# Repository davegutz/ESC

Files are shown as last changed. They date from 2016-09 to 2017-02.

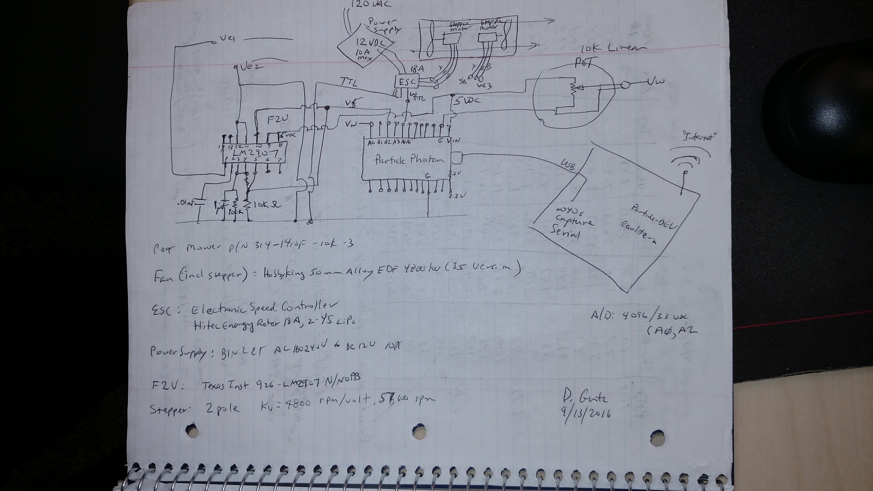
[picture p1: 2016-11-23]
Problem/2016-10-06 06.58.16.jpg

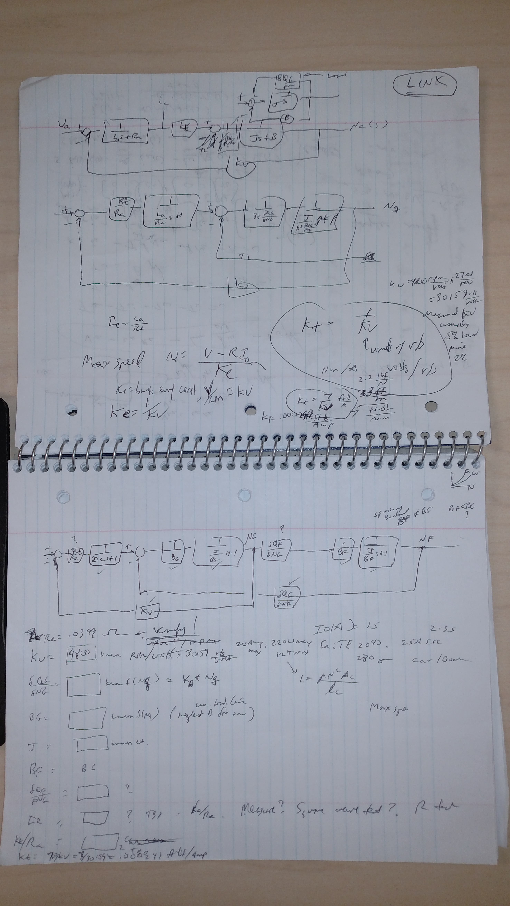
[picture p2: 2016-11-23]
Problem/2016-10-17 16.06.20.jpg

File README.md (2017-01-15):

Configuring Visual Studio Code IDE to run with Particle Photon
  https://www.hackster.io/gusgonnet/use-visual-studio-code-for-your-particle-development-needs-9e23bc
1.  Update particle IDE
    https://binaries.particle.io/cli/installer/windows/ParticleCLISetup.exe
	npm install -g particle-cli
2.  Download/install VS Code
	a.   Install from https://code.visualstudio.com/
	b.  Execute from command line providing proect path:
		$ code /home/gustavo/myParticleProject
		This can also be done from File menu of VS IDE
	c.  Install C/C++ Extension from Getting Started of https://code.visualstudio.com/docs/languages/cpp
	d.	Configure the c_cpp_properties.json file following instruction from same place of previous line
		browse to a .cpp file that has a #include.   You will see squiggly green line underneath.  Click on the text that is undelined.
		click the lightbulb that appears.   Click "Add include path to settings"
	e.  Generate a tasks.json file following instructions same place
		open Command Palette (ctrl-shift-P)
		select Tasks:  Configure Task Runner
		select Others
		Change "command" to the cmd line expression used to build ""
In the tasks.json (.vscode folder in MYWINDCODE) make it look like following (for usb flashing)
{ 
"version": "0.1.0", 
"command": "particle", 
"isShellCommand": true, 
"args": [], 
"showOutput": "always", 
"echoCommand": true, 
"tasks": [ 
{ 
    "taskName": "compile", 
    "suppressTaskName": false, 
    "isBuildCommand": true,
    "args": ["photon", "${workspaceRoot}", "--saveTo", "${workspaceRoot}/firmware.bin"]             
}, 
{ 
    "taskName": "flash",             
    "suppressTaskName": false, 
    "isTestCommand": true, 
    "args": ["--usb", "firmware.bin"] 
}    
]     
} 

	f.  Format your code by right-click - Format Code
	g.  Build by ctrl-shift-B
	h.  Flash by ctrl-P, task - <space> - <flash>
		Photon must be blinking yellow by pushing both buttons simultaneously, releasing RESET, wait for purple then yellow

1.       If compile in DEV and no status message returned, probably are not connected to wifi.  Particle-DEV does not work over GE network.

2.       Wifi connection problems at work usually fixed by changing Odyssey from BLUESSO to Internet.   Particle-DEV does not work over GE network.

4.       Photon does not connect for flash:   need to get closer to Internet wifi.   Photon wifi a little weak.

5.       Coolterm “Port not found.”  Photon USB not visible.  Restart Coolterm.   Unplug Photon USB and replug.   Rescan ports in Coolterm-Connection-Options.   Prevent this by disconnecting CoolTerm before servicing Photon.

6.       Red error window pops in DEV.  Restart DEV.

Compile Photon.
	- use MS Visual Studio IDE
	- ctr-Shift-B #to build
	- ctrl-P task flash #to flash
Communicate with photon real time
	- Cool Term - Connection - Send String
		b    # bare photon toggle
		t    # close loop with model toggle
		c    # closed loop toggle
		P 20 # request potThrottle 20 deg, open or closed work
		V 	 # run VECT toggle
		R 	 # run RAMP toggle
		f 	 # run freq resp toggle

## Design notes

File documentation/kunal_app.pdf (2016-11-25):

ECE 480 – Application Note – Kunal Verma | 4/2/2010

# Configuring a Frequency to Voltage Converter

by

## Kunal Verma

## Design Team 5

## ECE 480 - Spring 2010

## Michigan State University

## _______________________________ Introduction

Measuring frequency for use in signal processing is a very important tool for system

engineers. The most familiar type of tachometer is the speedometer used in motor

vehicles. One of the easiest ways to do this is to use a circuit that takes a varied frequency

input and produces a voltage corresponding to each frequency in the range of its

measuring capacity. By creating a linear relationship between frequency and voltage a

designer can vary easily integrate frequency measurement into the application of their

choice. In this article we will look at a method for designing an easy to use frequency to

voltage converter using the National Semiconductor LM2907/LM2917 series ICs.

## _________________________________ LM2907N

The specific IC model that we will analyze in this article is the LM2907-N, a 14-pin DIP

package that contains a comparator, capacitor charge pump, and op-amp/transistor

amplification stage. The schematic for the device can be seen below:

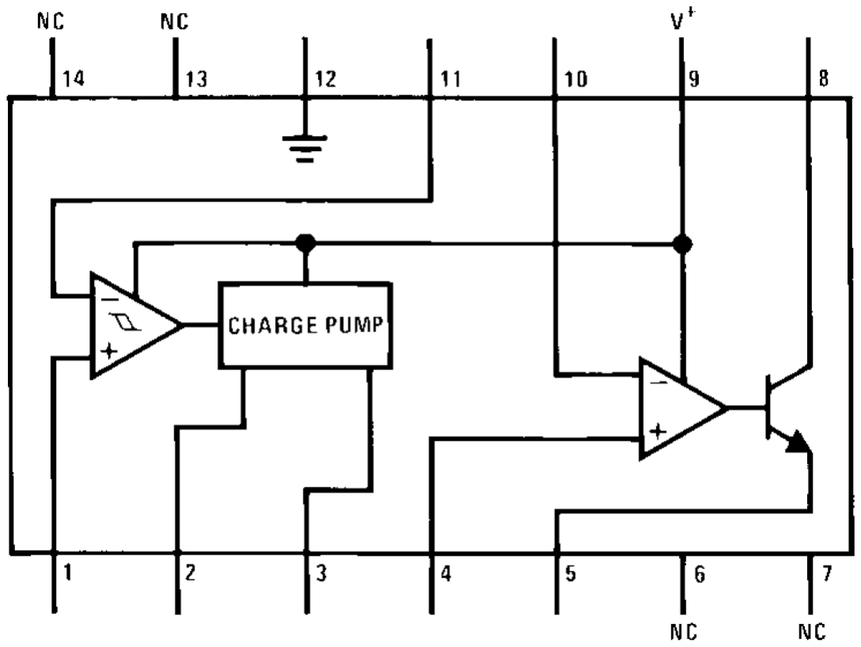
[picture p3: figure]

Figure 1: Circuit Layout for LM2907-N

The first part of the processing chain is the comparator. By grounding the negative

differential input of the comparator we create a zero-crossing detector. Applying an AC

signal with no DC offset and common grounding to the positive terminal will produce a

square wave output.

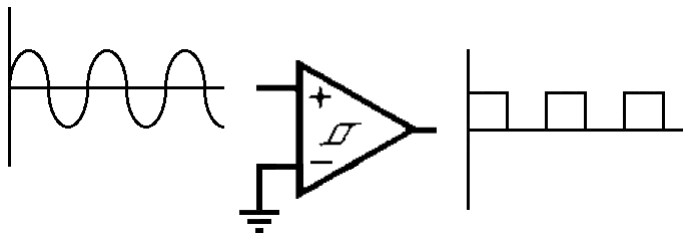
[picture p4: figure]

Figure 2: Output response of a zero-crossing detector

From this square wave the charge pump uses a timing capacitor to provide the charge and

discharge for the charge pumping action. The charging capacitor is attached to pin 2.

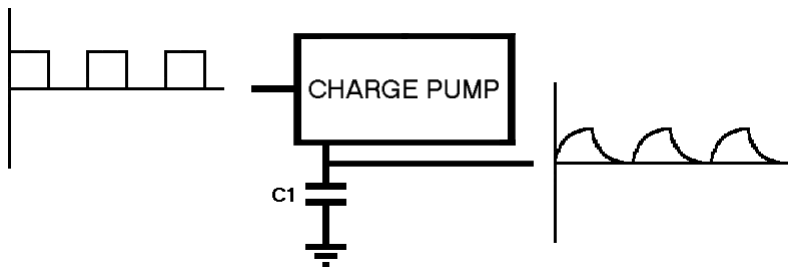
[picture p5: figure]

Figure 3: Voltage response of the timing capacitor C1

The amplitude of the resulting signal is | | ⁄ and a change in voltage of this magnitude
is experienced by the capacitor every | ( ⁄ | ) seconds. This results in a time averaging

current through the capacitor:

(1)

This current is then mirrored on the output of the charge pump where it can be fed to a

grounding resistor and filtered by a second capacitor for smoother response. The output

voltage across the resistor can then be calculated using Ohm’s law and Eq (1):

(2)

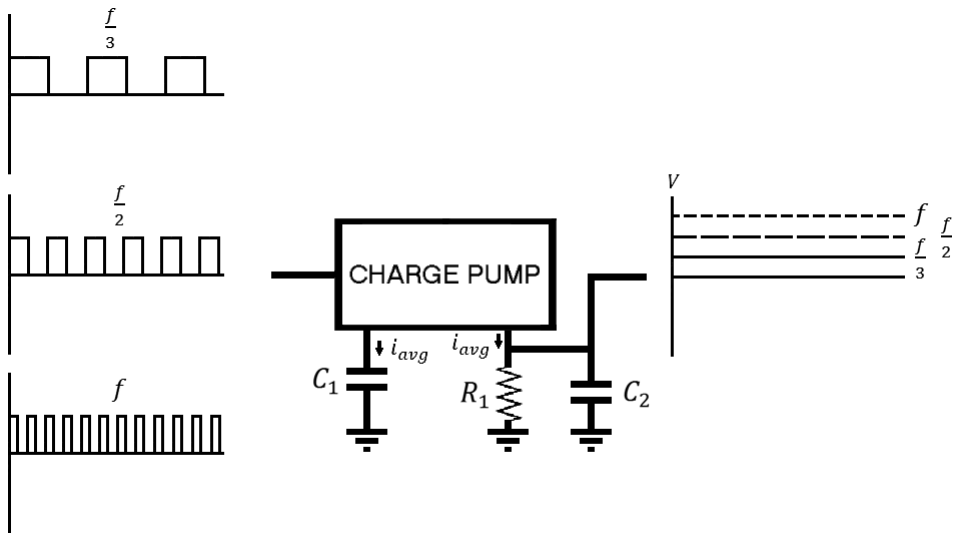
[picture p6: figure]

Figure 4: Expected output response of a charge pump

As we can see the output voltage is entirely affected by the frequency of the input signal

in a very simple linear relationship. In our application Vcc = 5V and we wish to see a

maximum output voltage of 5V as well, therefore we are given a simple design equation

relating our component values to the maximum expected frequency of our input signal.

(3)

Choosing a value for is relatively trivial. For low frequency signal acquisition the

general rule of thumb is to increase discharge time as much as possible, this reduces

response time for the frequency to voltage converter but it also stabilizes the output

voltage variation.

## __________________________________ Example

For our project we required a frequency to voltage converter with a 450 Hz range, and

output voltage of 5V. Using the assumption from before ( | )we can easily find

a relationship between the timing capacitor and output resistor using Eq (3).

choosing | nF:
( | )
The closest available resistor for use in our example is a 68 | resistor. Our

maximum frequency then becomes:

( | ) ( | )

Hz

Using Eq (2) we can also very easily calculate the linear relationship between input

frequency and output voltage, with DC corresponding to 0V as a minimum limit and

corresponding to Vcc as a maximum limit:

In order to compensate for any irregularities in the test circuit we choose to include

calibration variables. These variables will allow us to adapt our model for use in

integration with a microcontroller:

(

)

## _____________________________ Benchmarking

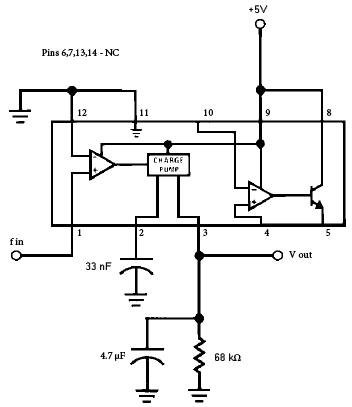
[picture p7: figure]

The test circuit used for the analysis of the

frequency to voltage converter is shown to

the right. With our compensation variables

set to 0 we expected an f-V relationship of
(

) .

The input signal for testing was a 1Vpp

Sine wave with 0-DC and variable

frequency (0 – 400 Hz). Frequencies

beyond 400 Hz showed a flat response, a

result we had not expected. The expected

and measured voltage response is shown in

Figure 6 below. Comparison between the

expected and measured functions led to

determination of the calibration variables:

and

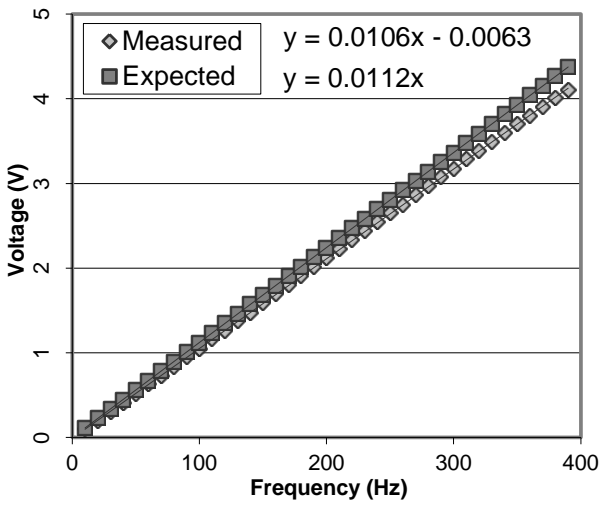
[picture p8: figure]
Voltage (V); Frequency (Hz); Measured Expected

Figure 6: Testing Results

Figure 5: Test Circuit for 450 Hz Frequency to

## _________________________________ Resources

National Conductor LM2907 Datasheet (http://www.national.com/ds/LM/LM2907.pdf)

The Analysis and Design of Linear Circuits – 6

th
Edition (Thomas and Albert, 2006)

Charge Pump Circuit Design – 1

st
Edition (Pan, 2006)

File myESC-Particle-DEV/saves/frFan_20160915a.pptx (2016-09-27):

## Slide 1

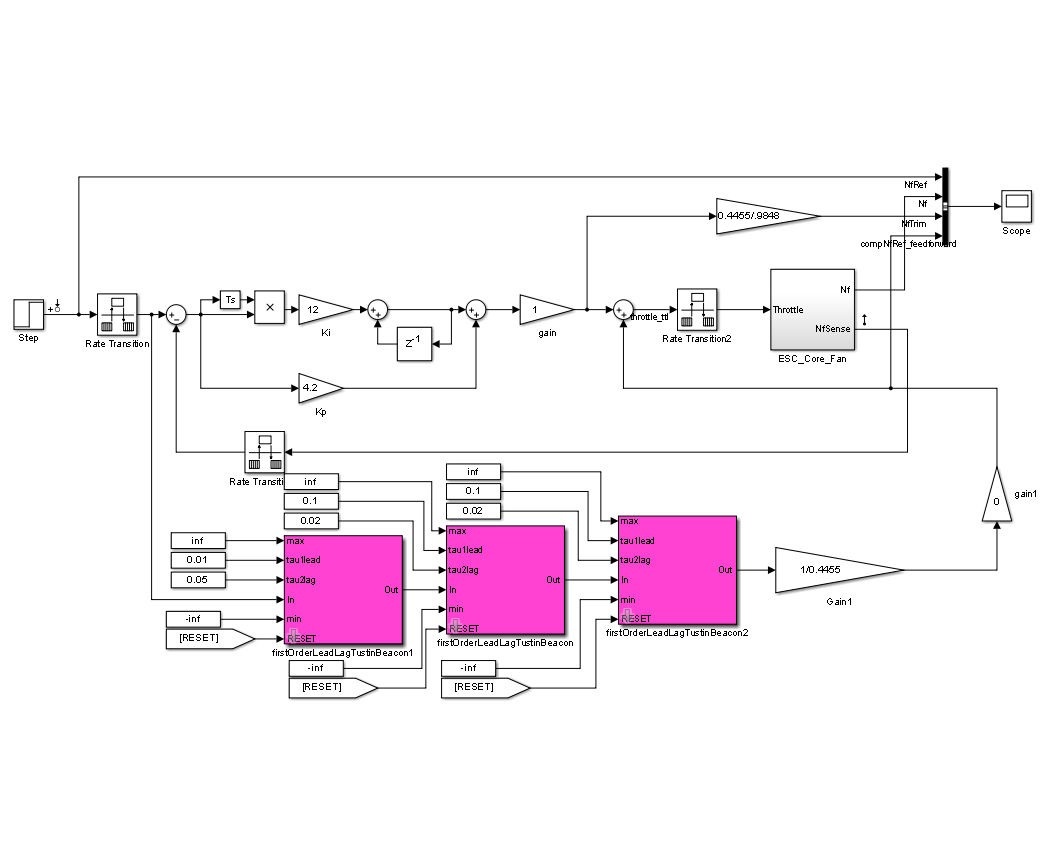
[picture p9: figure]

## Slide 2

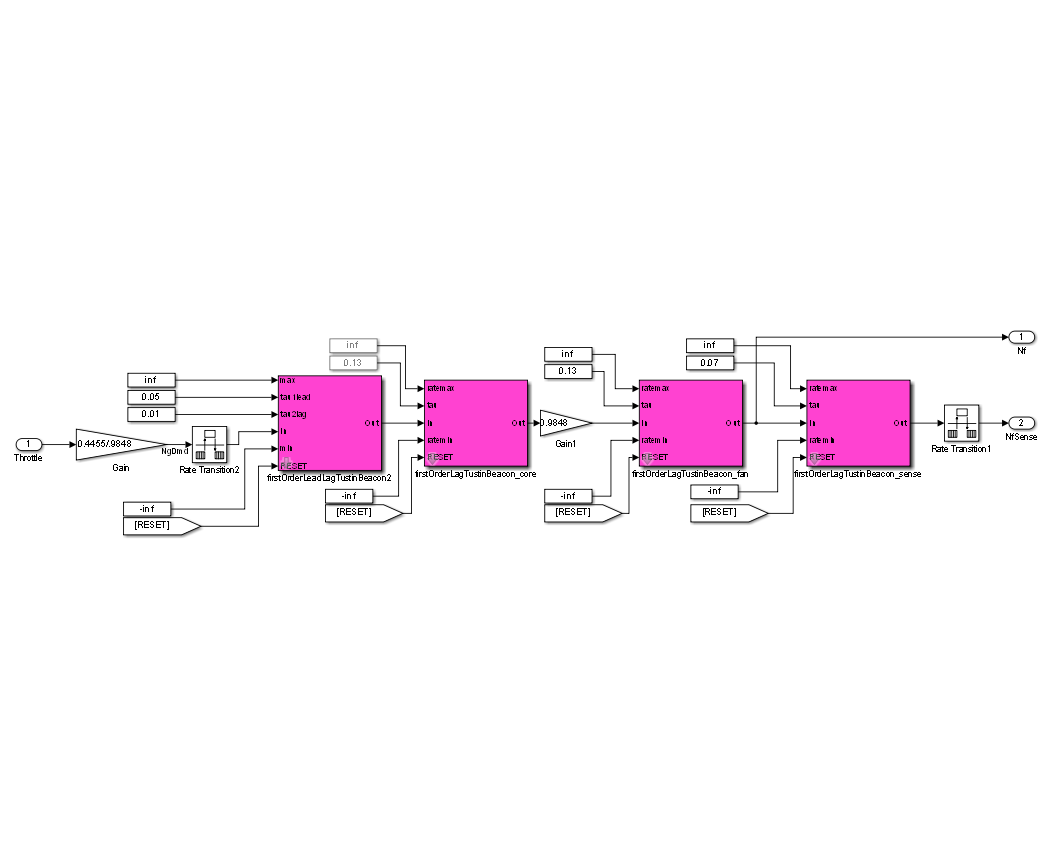
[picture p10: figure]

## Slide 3

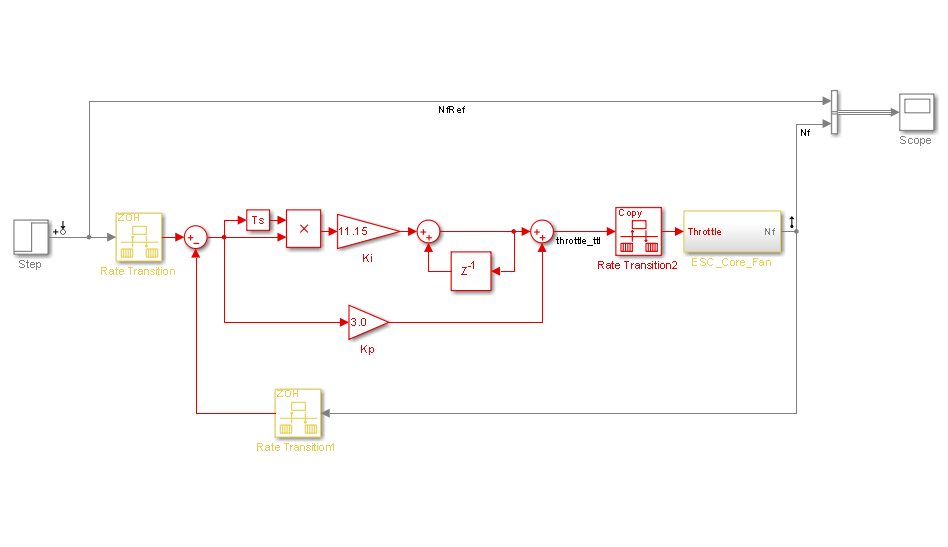
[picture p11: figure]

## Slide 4

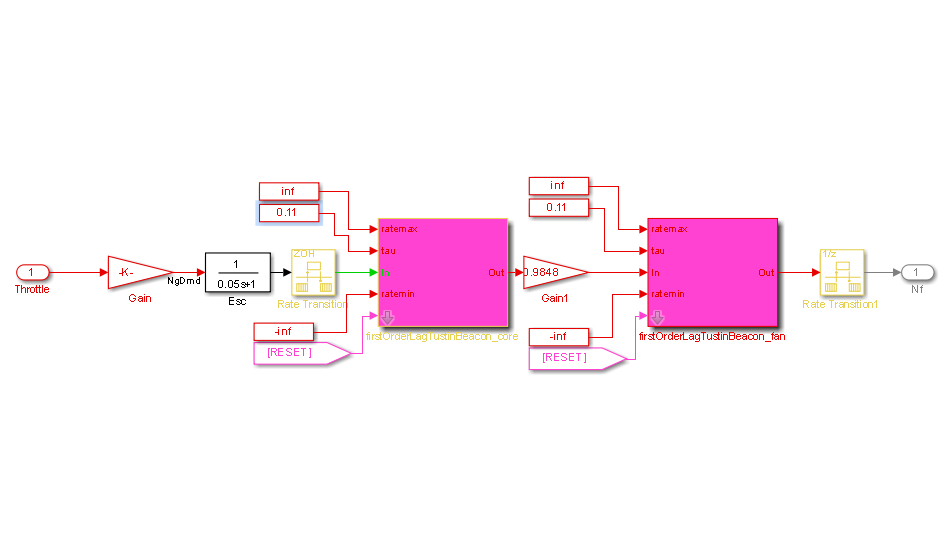
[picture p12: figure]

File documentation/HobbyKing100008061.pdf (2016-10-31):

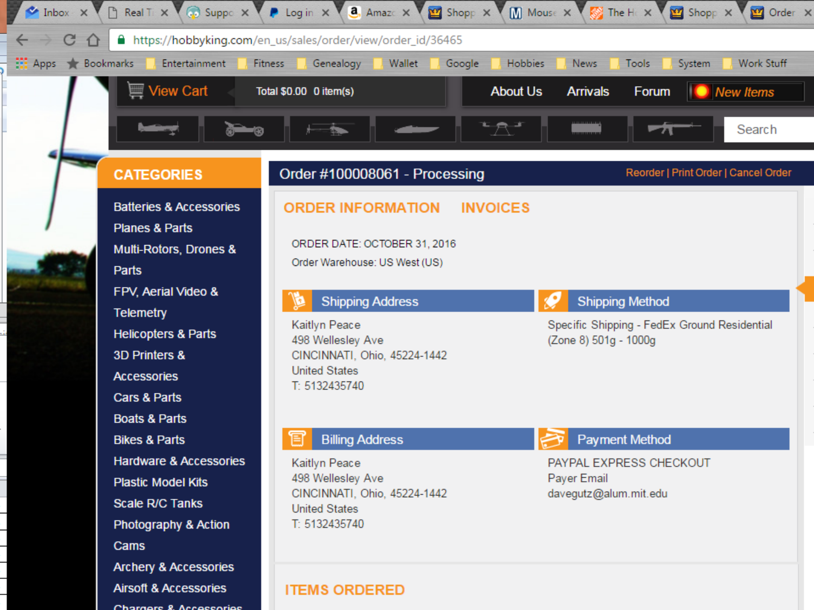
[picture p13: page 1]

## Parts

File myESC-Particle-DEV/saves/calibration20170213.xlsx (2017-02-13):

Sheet: Ard0_Turn0_ESC0_G0b_T0a
Description | Set Nt | TTL, ms | throttleFlt, deg | v4, vdc | Charger V, vdc | Charger I, A | Tng, micros | Ttur, micros |  | Charger Pwr, W | Throttle, deg | ln(Throttle) | FreqNg, Hz | FreqTur, Hz | Ng, RPM | Nt, RPM | Ng, % | Nt, % | Throttle, deg | Charger Pwr, W | Ng Pwr, W | Ng Pwr, SHP | Ng Total Torque, ft-lbf | Ng Torque, ft-lbf | Thrust, N | Thrust Power, W | Overall Efficiency | Vw, m/s | Vw, mph | Vt, m/s | Lambda tip speed ratio | dCpdLambda | simulate vpot from throttle | model throttle from vpot | Model Ng from Model Throttle, rpm | Model Ng from Model Throttle, % | Model pcntRef from Model Ng, % | Model Ng from pcntRef at RESET, % | Model Nt from Model Ng, % | Model Nt from Model Ng, rpm | Model Qg from Model Ng, ft-lbf | Model PwrG from Model Ng*Q, shp | Model dQgdNg, ft-lbf/rpm | Model TauG | Model dQtdNt, ft-lbf/rpm | Model TauT from wind | v4, vdc
DC Power Overhead | n/a | 1.03 | 6.07 | 0.0032 | 12.24 | 0.019 | 1e+32 | 1e+32 |  | 0.2 | 6.07 | 1.8027 | 1e-26 | 1e-26 | 6e-25 | 0 | 1.302083333e-27 | 0 | 6.066122035 | 0.23 | 0 | 0.0000 | 0.00000 | 0.00000 | 9.768434808e-87 | 9.469612349e-129 |  | 1.938818764e-42 | 4.362342218e-42 | 0 | 0.00 |  | 0.169 | 6.066 | 0.00 | 0.00 | -17.48 | 0.03 |  | 0 |  |  |  |  |  |  | 0.0032
Lowest Ng | n/a | 1.05 | 9 | 0.0024 | 12.15 | 0.34 | 7080 | 1e+32 |  | 4.1 | 9 | 2.1972 | 141.2429379 | 1e-26 | 8474.576271 | 6e-25 | 18.39100753 | 1.302083333e-27 | 9 | 4.07 | 3.83769 | 0.0051 | 0.00319 | 0.00000 | 0.028 | 0.04 | 1.1 | 3.25 | 7.3 | 1.727875959e-27 | 5.309152921e-28 |  | 0.250 | 9.000 | 4918.12 | 10.67 | -7.36 | 10.70 |  | 0 | 0.00000 | 0.00000 | 1.105647023e-07 |  |  |  | 0.0024
First Nt | tbd | 1.11 | 20 | 0.069 | 12.14 | 0.86 | 4040 | 68000 |  | 10.5 | 20 | 2.9957 | 247.5247525 | 14.70588235 | 14851.48515 | 882.3529412 | 32.22978548 | 1.914828431 | 20 | 10.45 | 10.22 | 0.0137 | 0.00485 | 0.00166 | 0.148 | 0.56 | 5.4 | 7.55 | 17.0 | 2.5 | 0.34 |  | 0.556 | 20.000 | 14872.75 | 32.28 | 13.10 | 32.29 | 13.1 | 6038.54 | 0.00194 | 0.00548 | 3.729326807e-07 | 0.100 |  |  | 0.069
Dynamic Nt #1 | 16 | 1.14 | 25 | 0.51 | 12.14 | 1.13 | 3680 | 8500 |  | 13.7 | 25 | 3.2189 | 271.7391304 | 117.6470588 | 16304.34783 | 7058.823529 | 35.38269928 | 15.31862745 | 25 | 13.72 | 13.49 | 0.0181 | 0.00583 | 0.00264 | 0.196 | 0.85 | 6.2 | 8.68 | 19.5 | 20.3 | 2.34 |  | 0.694 | 25.000 | 17654.58 | 38.31 | 18.82 | 38.33 | 18.8 | 8674.185965 | 0.00308 | 0.01034 | 4.462516013e-07 | 0.084 | -1.105608516e-07 | 0.339 | 0.51
Dynamic Nt #2 | 20 | 1.19 | 35 | 0.801 | 12.11 | 1.838 | 2980 | 5420 |  | 22.3 | 35 | 3.5553 | 335.5704698 | 184.501845 | 20134.22819 | 11070.1107 | 43.69407159 | 24.02367774 | 35 | 22.26 | 22.03 | 0.0295 | 0.00770 | 0.00452 | 0.369 | 2.20 | 9.9 | 11.92 | 26.8 | 31.9 | 2.67 |  | 0.972 | 35.000 | 21849.23 | 47.42 | 27.45 | 47.43 | 27.4 | 12648.40654 | 0.00518 | 0.02155 | 5.568072553e-07 | 0.067 | -1.517220518e-07 | 0.247 | 0.801
Dynamic Nt #3 | 25 | 1.30 | 54 | 1.167 | 12.06 | 3.18 | 2390 | 3740 |  | 38.4 | 54 | 3.9890 | 418.4100418 | 267.3796791 | 25104.60251 | 16042.78075 | 54.4804742 | 34.81506239 | 54 | 38.35 | 38.12 | 0.0511 | 0.01069 | 0.00750 | 0.716 | 5.94 | 15.5 | 16.59 | 37.3 | 46.2 | 2.78 |  | 1.500 | 54.000 | 27255.18 | 59.15 | 38.56 | 59.15 | 38.6 | 17770.27059 | 0.00857 | 0.04450 | 6.992882824e-07 | 0.054 | -2.112400453e-07 | 0.177 | 1.167
Dynamic Nt #4 | 36 | 1.36 | 64 | 1.275 | 12.03 | 3.96 | 2170 | 3260 |  | 47.6 | 64 | 4.1589 | 460.8294931 | 306.7484663 | 27649.76959 | 18404.90798 | 60.00384025 | 39.94120654 | 64 | 47.64 | 47.41 | 0.0636 | 0.01208 | 0.00889 | 0.956 | 9.17 | 19.2 | 19.18 | 43.2 | 53.0 | 2.76 |  | 1.778 | 64.000 | 29373.23 | 63.74 | 42.92 | 63.75 | 42.9 | 19777.02234 | 0.01011 | 0.05657 | 7.551124993e-07 | 0.050 | -2.441650521e-07 | 0.153 | 1.275
Dynamic Nt #5 | 45 | 1.50 | 90 | 1.597 | 11.95 | 5.94 | 1860 | 2690 |  | 71.0 | 90 | 4.4998 | 537.6344086 | 371.7472119 | 32258.06452 | 22304.83271 | 70.00448029 | 48.40458488 | 90 | 70.98 | 70.75 | 0.0949 | 0.01545 | 0.01226 | 1.518 | 18.35 | 25.8 | 24.17 | 54.4 | 64.2 | 2.658 |  | 2.500 | 90.000 | 33623.41 | 72.97 | 51.66 | 72.97 | 51.7 | 23803.85519 | 0.01356 | 0.08682 | 8.67131732e-07 | 0.043 | -3.076831315e-07 | 0.122 | 1.597
Dynamic Nt #6 | 50 | 1.69 | 125 | 1.95 | 11.84 | 8.59 | 1620 | 2210 |  | 101.7 | 125 | 4.8283 | 617.2839506 | 452.4886878 | 37037.03704 | 27149.32127 | 80.3755144 | 58.91779789 | 125 | 101.71 | 101.47 | 0.1361 | 0.01930 | 0.01611 | 2.298 | 34.16 | 33.6 | 29.73 | 66.9 | 78.2 | 2.629 |  | 3.472 | 125.000 | 37718.72 | 81.85 | 60.08 | 81.85 | 60.1 | 27683.96023 | 0.01733 | 0.12449 | 9.750692614e-07 | 0.038 | -3.785302413e-07 | 0.099 | 1.95
Dynamic Nt #7 | 52 | 1.86 | 155 | 2.26 | 11.66 | 12.52 | 1430 | 1900 |  | 146.0 | 155 | 5.0434 | 699.3006993 | 526.3157895 | 41958.04196 | 31578.94737 | 91.05477855 | 68.53070175 | 155 | 145.98 | 145.75 | 0.1955 | 0.02447 | 0.02128 | 3.341 | 59.89 | 41.0 | 35.85 | 80.7 | 90.9 | 2.536 | -0.425 | 4.306 | 155.000 | 40400.42 | 87.67 | 65.59 | 87.67 | 65.6 | 30224.73471 | 0.02004 | 0.15419 | 1.045749028e-06 | 0.036 | -4.564246037e-07 | 0.082 | 2.26
Dynamic Nt #7 | 52 | 1.92 | 165 | 2.34 | 11.56 | 14.28 | 1380 | 1815 |  | 165.1 | 165 | 5.1059 | 724.6376812 | 550.9641873 | 43478.26087 | 33057.85124 | 94.35386473 | 71.74012856 | 165 | 165.08 | 164.84 | 0.2211 | 0.02670 | 0.02351 | 3.717 | 70.29 | 42.6 | 37.82 | 85.1 | 95.2 | 2.517 | -0.400 | 4.583 | 165.000 | 41179.84 | 89.37 | 67.19 | 89.36 | 67.2 | 30963.18996 | 0.02087 | 0.16361 | 1.066291522e-06 | 0.035 | -4.814536392e-07 | 0.078 | 2.34
Max | tbd | 2.00 | 180 | 2.4 | 11.53 | 14.92 | 1368 | 1790 |  | 172.0 | 180 | 5.1930 | 730.994152 | 558.6592179 | 43859.64912 | 33519.55307 | 95.18153021 | 72.74208566 | 180 | 172.03 | 171.80 | 0.2304 | 0.02759 | 0.02440 | 4.425 | 91.30 | 53.1 | 41.26 | 92.8 | 96.5 | 2.339 |  | 5.000 | 180.000 | 42264.57 | 91.72 | 69.42 | 91.71 | 69.4 | 31990.91934 | 0.02204 | 0.17736 | 1.094881102e-06 | 0.034 | -5.253091111e-07 | 0.071 | 2.4
Calibration sheet
1 |  | Calibrate the ESC first |  |  |  |  |  | Key | User Inputs
2 |  | Update the Arduino software |  |  |  |  |  |  | Derived
3 |  | Run the points below |  |  |  |  |  |  | Entry to myCLAW.h and potESC.ino
4 |  | Enter blue highlighted items into myCLaw.h |  |  |  |  |  |  | Entry to myCLAW.h and potESC.ino; same between units
5 |  | Run the frequency response fr_
6 |  | Enter results of fr_ into table lower right corner this sheet
7 |  | Hand tune DELTAV |  |  |  |  |  |  |  |  |  |  |  |  | // Constants always defined - potESC.ino #ifdef Arduino
8 |  | Check that Nt corresponding to entry in column AG lines up with Nt from Z in Tau data |  |  |  |  |  |  |  |  |  |  |  |  | POT_MAX | 5 |  |  | v
 |  |  |  |  |  |  |  |  |  |  |  |  |  |  | F2V_MAX | 5 |  |  | v
Motor | numPoles | 1 |  |  |  |  |  | Inertia Turbine Only (need motor***) |  |  |  |  |  |  | F2V_MIN | 0 |  |  | v
 | Kv | 4800 | rpm/V |  |  |  |  | Rt= | 25 | mm |  |  |  |  | POT_MIN | 0 |  |  | v
 | Vc | 12 |  |  |  |  |  | Mt= | 2.1797 | gm |  |  |  |  | DENS_SI | 1.225 |  |  | kg/m^3
 | Ra | 0.0399 | O |  |  |  |  | Jt= | 0.001548498305 | lbm-in^2 | 1/3*MR^2
 | La | 4.2e-06 | H |  |  |  |  | Rm= | 4.8 | mm | at most |  |  |  | // See calibration<date>.xlsx - myCLAW.h
 | Power | 240 | W max |  |  |  |  | Lm= | 19.0 | mm | at most |  |  |  | RPM_P | 460.8 |  |  | rpm/%
 | Kvrps | 502.7 | r/s / V |  |  |  |  | Mm= | 0.006212622191 | lbm | at most |  |  |  | THTL_MAX | 180 |  |  | deg
 | Kt | 0.0139 | ft-lbf/A |  |  |  |  | Jm | 0.0001092062495 | lbm-in^2 | 1/2*MR^2 |  |  |  | THTL_MIN | 0 |  |  | deg
 | Fn | 0.99 | lbf |  |  |  |  | J= | 0.001657704555 | lbm-in^2 |  |  |  |  | AREA_SI | 0.002121360439 |  |  | m^2
 |  |  |  |  |  |  |  | J= | 1.151183719e-05 | lbm-ft^2 |  |  |  |  | NM_2_FTLBF | 0.738 |  |  | ft-lbf/N-m
LM2907N Circuit |  | vf2v, v |  |  |  |  |  | J= | 3.74268175e-08 | ft-lbf/(rpm/sec) |  |  |  |  | JT | 3.74268175e-08 |  |  | rpm/s / ft-lbf
 | F2V_MIN | 0 |  |  |  |  |  |  |  |  |  |  |  |  | D_SI | 0.055 |  |  | m
 | F2V_MAX | 5 |  |  |  | TBD |  | From fr_a0_t0_e0_g0b_t0a.xlsx |  |  |  |  |  |  | FG_SI | 4.425 |  |  | N
 |  |  |  |  |  |  |  | Nt, % | Calc Ng, % | Meas TauT0, s | Meas QdN, ft-lbf/rpm | Meas dQdN, N-m/rpm
Fan Rotor | Dia | 55 | mm |  |  |  |  | 83.9 | 107.0 | 0 |  |  |  |  | // Ard0_Turn0_ESC0_G0b_T0a - myCLAW.h
 | Dia spinner | 18 | mm |  |  |  |  | 62 | 83.9 | 0.050 |  |  |  |  | P_V4_NT | 0 | 13952.04806 | 27.10040275 | rpm
 |  |  |  |  |  |  |  | 48 | 69.1 | 0.082 | 4.564246037e-07 | -6.187291928e-07 | cal point |  | P_LT_NG | -22473.69517 | 12466.55113 |  | rpm
Air | Dens | 1.225 | kg/m^3 | SLS Std Day |  |  |  | 25 | 44.8 | 0.196 |  |  |  |  | P_NG_NT | -8052.654718 | 0.9475 |  | rpm
 |  |  |  |  |  |  |  | 16 | 35.3 | 0.249 |  |  |  |  | P_NT_NG | 8510.224957 | 1.0550 |  | rpm
Thtl | min | 0 | V Pot |  |  |  |  | -26.6 | -9.6 | 0.5 |  |  |  |  | DCPDL | -0.425 |  |  | none
 | max | 5 | V Pot |  |  |  |  |  |  |  |  |  |  |  | LAMBDA | 2.54 |  |  | none
 | min | 0 | deg Throttle |  |  |  |  |  |  |  |  |  |  |  | DELTAV | 0 |  |  | m/s
 | max | 180 | deg Throttle |  |  |  |  | P_NG_QG | -0.000695441078 | -1.905896073e-08 | 1.317817906e-11 | ft-lbf
Adjust | 1.25 | for 100% Ng at |  | 240 | watts |  |  | matlabTuning.xlsx |  |  |  | tldF=.15, tlgF=.03
 |  |  |  |  |  |  |  | TauT Design, s | Nt, % | TLD_S | LG_S | TLD_L | LG_L |  | xAll | 0.0 | -0.1 | 27.2 | 47.4 | 75.1 | 80.0
 |  |  |  |  |  |  |  | 0 | 83.9 | 0.2 | 4.4 | 0.09 | 5 |  | TLD_S | 0.475 | 0.475 | 0.325 | 0.225 | 0.200 | 0.200 | Scheduled
 |  |  |  |  |  |  |  | 0.02 | 75.1 | 0.2 | 3.75 | 0.09 | 5 |  | LG_S | 2.40 | 2.40 | 2.70 | 3.20 | 3.75 | 4.40
 |  |  |  |  |  |  |  | 0.085 | 47.4 | 0.225 | 3.2 | 0.125 | 4.050 |  | tldF | 0.15
 |  |  |  |  |  |  |  | 0.185 | 27.2 | 0.325 | 2.7 | 0.24 | 3.75 |  | tlgF | 0.03
 |  |  |  |  |  |  |  | 0.344 | -0.1 | 0.475 | 2.4 | 0.42 | 3.6 |  | TLD_L | 0.420 | 0.420 | 0.240 | 0.125 | 0.090 | 0.090 | Fixed lead
 |  |  |  |  |  |  |  | 0.5 | -26.6 | 0.475 | 2.4 | 0.42 | 3.6 |  | LG_L | 3.60 | 3.60 | 3.75 | 4.05 | 5.00 | 5.00

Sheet: Ard1_Turn1x_ESC1_G1b_T1a
Description | Set Nt | TTL, ms | throttleFlt, deg | v4, vdc | Charger V, vdc | Charger I, A | Tng, micros | Ttur, micros |  | Charger Pwr, W | Throttle, deg | ln(Throttle) | FreqNg, Hz | FreqTur, Hz | Ng, RPM | Nt, RPM | Ng, % | Nt, % | Throttle, deg | Charger Pwr, W | Ng Pwr, W | Ng Pwr, SHP | Ng Total Torque, ft-lbf | Ng Torque, ft-lbf | Thrust, N | Thrust Power, W | Overall Efficiency | Vw, m/s | Vw, mph | Vt, m/s | Lambda tip speed ratio | dCpdLambda | simulate vpot from throttle | model throttle from vpot | Model Ng from Model Throttle, rpm | Model Ng from Model Throttle, % | Model pcntRef from Model Ng, % | Model Ng from pcntRef at RESET, % | Model Nt from Model Ng, % | Model Nt from Model Ng, rpm | Model Qg from Model Ng, ft-lbf | Model PwrG from Model Ng*Q, shp | Model dQgdNg, ft-lbf/rpm | Model TauG | Model dQtdNt, ft-lbf/rpm | Model TauT from wind | v4, vdc
DC Power Overhead | n/a | 1.03 | 5.38 | 0.0032 | 12.24 | 0.019 | 1e+32 | 1e+32 |  | 0.2 | 5.38 | 1.6827 | 1e-26 | 1e-26 | 6e-25 | 0 | 1.302083333e-27 | 0 | 5.380330042 | 0.23 | 0 | 0.0000 | 0.00000 | 0.00000 | 9.768434808e-87 | 9.469612349e-129 |  | 1.938818764e-42 | 4.362342218e-42 | 0 | 0.00 |  | 0.149 | 5.380 | 0.00 | 0.00 | -12.59 | 0.04 |  | 0 |  |  |  |  |  |  | 0.0032
Lowest Ng | n/a | 1.04 | 8 | 0.0046 | 12.23 | 0.28 | 8000 | 1e+32 |  | 3.4 | 8 | 2.0794 | 125 | 1e-26 | 7500 | 6e-25 | 16.27604167 | 1.302083333e-27 | 8 | 3.39 | 3.15515 | 0.0042 | 0.00296 | 0.00000 | 0.019 | 0.03 | 0.8 | 2.71 | 6.1 | 1.727875959e-27 | 6.376910601e-28 |  | 0.222 | 8.000 | 4555.17 | 9.89 | -2.93 | 9.92 |  | 0 | 0.00000 | 0.00000 | 2.827231837e-07 |  |  |  | 0.0046 |  | -12.400000
First Nt | tbd | 1.07 | 12 | 0.238 | 12.25 | 0.53 | 5540 | 13200 |  | 6.5 | 12 | 2.4849 | 180.5054152 | 75.75757576 | 10830.32491 | 4545.454545 | 23.50330927 | 9.864267677 | 12 | 6.47 | 6.24 | 0.0084 | 0.00405 | 0.00109 | 0.057 | 0.14 | 2.1 | 4.70 | 10.6 | 13.1 | 2.78 |  | 0.333 | 12.000 | 9211.08 | 19.99 | 6.94 | 20.01 | 6.9 | 3198.660363 | 0.00033 | 0.00058 | 3.695740461e-07 | 0.101 |  |  | 0.238 |  | 72.50000
Dynamic Nt #1 | 16 | 1.09 | 17 | 0.434 | 12.24 | 0.655 | 4900 | 10000 |  | 8.0 | 17 | 2.8332 | 204.0816327 | 100 | 12244.89796 | 6000 | 26.57312925 | 13.02083333 | 17 | 8.02 | 7.78 | 0.0104 | 0.00448 | 0.00151 | 0.083 | 0.23 | 2.9 | 5.65 | 12.7 | 17.3 | 3.06 |  | 0.472 | 17.000 | 13210.65 | 28.67 | 15.42 | 28.69 | 15.4 | 7105.794506 | 0.00196 | 0.00492 | 4.44181543e-07 | 0.084 |  |  | 0.434
Dynamic Nt #2 | 20 | 1.12 | 21 | 0.586 | 12.24 | 0.877 | 4180 | 7500 |  | 10.7 | 21 | 3.0445 | 239.2344498 | 133.3333333 | 14354.06699 | 8000 | 31.15031898 | 17.36111111 | 21 | 10.73 | 10.50 | 0.0141 | 0.00515 | 0.00219 | 0.134 | 0.48 | 4.5 | 7.17 | 16.1 | 23.0 | 3.21 |  | 0.583 | 21.000 | 15637.09 | 33.93 | 20.56 | 33.95 | 20.6 | 9476.15657 | 0.00309 | 0.00920 | 4.89444074e-07 | 0.076 | -1.031450924e-07 | 0.363 | 0.586 | 0.44 | -8.506094887e-08
Dynamic Nt #3 | 25 | 1.15 | 27 | 0.793 | 12.23 | 1.23 | 3540 | 5580 |  | 15.0 | 27 | 3.2958 | 282.4858757 | 179.2114695 | 16949.15254 | 10752.68817 | 36.78201507 | 23.33482676 | 27 | 15.04 | 14.81 | 0.0199 | 0.00615 | 0.00319 | 0.220 | 1.01 | 6.7 | 9.21 | 20.7 | 31.0 | 3.36 |  | 0.750 | 27.000 | 18522.91 | 40.20 | 26.68 | 40.21 | 26.7 | 12295.27891 | 0.00458 | 0.01615 | 5.43275771e-07 | 0.069 | -1.436319949e-07 | 0.261 | 0.793
Dynamic Nt #4 | 36 | 1.23 | 42 | 1.175 | 12.19 | 2.41 | 2770 | 3760 |  | 29.4 | 42 | 3.7377 | 361.0108303 | 265.9574468 | 21660.64982 | 15957.44681 | 47.00661853 | 34.62987589 | 42 | 29.38 | 29.15 | 0.0391 | 0.00948 | 0.00651 | 0.460 | 3.06 | 10.4 | 13.30 | 29.9 | 46.0 | 3.46 |  | 1.167 | 42.000 | 23596.43 | 51.21 | 37.44 | 51.21 | 37.4 | 17251.54263 | 0.00758 | 0.03404 | 6.37916604e-07 | 0.059 | -2.252395456e-07 | 0.166 | 1.175 | 0.289 | -1.295045588e-07
Dynamic Nt #5 | 45 | 1.37 | 67 | 1.624 | 12.13 | 4.27 | 2170 | 2810 |  | 51.8 | 67 | 4.2047 | 460.8294931 | 355.8718861 | 27649.76959 | 21352.31317 | 60.00384025 | 46.33748517 | 67 | 51.80 | 51.56 | 0.0691 | 0.01313 | 0.01017 | 0.956 | 9.17 | 17.7 | 19.18 | 43.2 | 61.5 | 3.206 |  | 1.861 | 67.000 | 28959.21 | 62.85 | 48.81 | 62.84 | 48.8 | 22490.37824 | 0.01127 | 0.06212 | 7.379532029e-07 | 0.051 | -3.424745996e-07 | 0.109 | 1.624
Dynamic Nt #7 | 52 | 1.44 | 79 | 1.786 | 12.09 | 5.32 | 2020 | 2560 |  | 64.3 | 79 | 4.3694 | 495.049505 | 390.625 | 29702.9703 | 23437.5 | 64.45957096 | 50.86263021 | 79 | 64.32 | 64.09 | 0.0859 | 0.01520 | 0.01223 | 1.185 | 12.65 | 19.7 | 21.36 | 48.0 | 67.5 | 3.161 | -0.830 | 2.194 | 79.000 | 30851.07 | 66.95 | 52.82 | 66.94 | 52.8 | 24338.52187 | 0.01270 | 0.07457 | 7.732438699e-07 | 0.048 | -3.858434794e-07 | 0.097 | 1.786
Dynamic Nt #8 | 55 | 1.47 | 84 | 1.842 | 12.08 | 5.63 | 1970 | 2480 |  | 68.0 | 84 | 4.4308 | 507.6142132 | 403.2258065 | 30456.85279 | 24193.54839 | 66.09560068 | 52.50336022 | 84 | 68.01 | 67.78 | 0.0909 | 0.01567 | 0.01271 | 1.278 | 14.17 | 20.8 | 22.17 | 49.9 | 69.7 | 3.142 |  | 2.333 | 84.000 | 31555.77 | 68.48 | 54.31 | 68.47 | 54.3 | 25026.92869 | 0.01324 | 0.07958 | 7.863891339e-07 | 0.048 | -4.021532182e-07 | 0.093 | 1.842 | 0.085 | -4.403155001e-07
Dynamic Nt #8 | 62 | 1.67 | 121 | 2.19 | 11.97 | 8.66 | 1650 | 2040 |  | 103.7 | 121 | 4.7958 | 606.0606061 | 490.1960784 | 36363.63636 | 29411.76471 | 78.91414141 | 63.82761438 | 121 | 103.66 | 103.43 | 0.1387 | 0.02003 | 0.01707 | 2.175 | 31.45 | 30.3 | 28.93 | 65.1 | 84.7 | 2.928 |  | 3.361 | 121.000 | 35746.72 | 77.58 | 63.20 | 77.56 | 63.2 | 29121.02568 | 0.01670 | 0.11369 | 8.645667232e-07 | 0.043 | -5.367879663e-07 | 0.070 | 2.19
Max | tbd | 1.97 | 175 | 2.66 | 11.7 | 14.72 | 1360 | 1620 |  | 172.2 | 175 | 5.1648 | 735.2941176 | 617.2839506 | 44117.64706 | 37037.03704 | 95.74142157 | 80.3755144 | 175 | 172.22 | 171.99 | 0.2306 | 0.02746 | 0.02449 | 4.425 | 91.30 | 53.0 | 41.26 | 92.8 | 106.7 | 2.585 |  | 4.861 | 175.000 | 39983.86 | 86.77 | 72.18 | 86.75 | 72.2 | 33260.23592 | 0.02054 | 0.15633 | 9.436057589e-07 | 0.040 | -7.827245676e-07 | 0.048 | 2.66 | 0.035 | -1.069337643e-06
Calibration sheet
1 |  | Calibrate the ESC first |  |  |  |  |  | Key | User Inputs
2 |  | Update the Arduino software |  |  |  |  |  |  | Derived
3 |  | Run the points below |  |  |  |  |  |  | Entry to myCLAW.h and potESC.ino
4 |  | Enter blue highlighted items into myCLaw.h |  |  |  |  |  |  | Entry to myCLAW.h and potESC.ino; same between units
5 |  | Run the frequency response fr_
6 |  | Enter results of fr_ into table lower right corner this sheet
7 |  | Hand tune DELTAV |  |  |  |  |  |  |  |  |  |  |  |  | // Constants always defined - potESC.ino #ifdef Arduino
8 |  | Check that Nt corresponding to entry in column AG lines up with Nt from Z in Tau data |  |  |  |  |  |  |  |  |  |  |  |  | POT_MAX | 5 |  |  | v
 |  |  |  |  |  |  |  |  |  |  |  |  |  |  | F2V_MAX | 5 |  |  | v
Motor | numPoles | 1 |  |  |  |  |  | Inertia Turbine Only (need motor***) |  |  |  |  |  |  | F2V_MIN | 0 |  |  | v
 | Kv | 4800 | rpm/V |  |  |  |  | Rt= | 25 | mm |  |  |  |  | POT_MIN | 0 |  |  | v
 | Vc | 12 |  |  |  |  |  | Mt= | 2.1797 | gm |  |  |  |  | DENS_SI | 1.225 |  |  | kg/m^3
 | Ra | 0.0399 | O |  |  |  |  | Jt= | 0.001548498305 | lbm-in^2 | 1/3*MR^2
 | La | 4.2e-06 | H |  |  |  |  | Rm= | 4.8 | mm | at most |  |  |  | // See calibration<date>.xlsx - myCLAW.h
 | Power | 240 | W max |  |  |  |  | Lm= | 19.0 | mm | at most |  |  |  | RPM_P | 460.8 |  |  | rpm/%
 | Kvrps | 502.7 | r/s / V |  |  |  |  | Mm= | 0.006212622191 | lbm | at most |  |  |  | THTL_MAX | 180 |  |  | deg
 | Kt | 0.0139 | ft-lbf/A |  |  |  |  | Jm | 0.0001092062495 | lbm-in^2 | 1/2*MR^2 |  |  |  | THTL_MIN | 0 |  |  | deg
 | Fn | 0.99 | lbf |  |  |  |  | J= | 0.001657704555 | lbm-in^2 |  |  |  |  | AREA_SI | 0.002121360439 |  |  | m^2
 |  |  |  |  |  |  |  | J= | 1.151183719e-05 | lbm-ft^2 |  |  |  |  | NM_2_FTLBF | 0.738 |  |  | ft-lbf/N-m
LM2907N Circuit |  | vf2v, v |  |  |  |  |  | J= | 3.74268175e-08 | ft-lbf/(rpm/sec) |  |  |  |  | JT | 3.74268175e-08 |  |  | rpm/s / ft-lbf
 | F2V_MIN | 0 |  |  |  |  |  |  |  |  |  |  |  |  | D_SI | 0.055 |  |  | m
 | F2V_MAX | 5 |  |  |  |  |  | From fr_a1_t1_e1_g1b_t1a.xlsx |  |  |  |  |  |  | FG_SI | 4.425 |  |  | N
 |  |  |  |  |  |  |  | Nt, % | Calc Ng, % | Meas TauT1, s | Meas QdN, ft-lbf/rpm | Meas dQdN, N-m/rpm
Fan Rotor | Dia | 55 | mm |  |  |  |  | 68.3 | 82.7 | 0 |  |  |  |  | // Ard1_Turn1x_ESC1_G1b_T1a - myCLAW.h
 | Dia spinner | 18 | mm |  |  |  |  | 62 | 76.3 | 0.030 |  |  |  |  | P_V4_NT | 0 | 12959.72295 | 264.0925319 | rpm
 |  |  |  |  |  |  |  | 48 | 62.0 | 0.097 | 3.858434794e-07 | -5.230494207e-07 | cal point |  | P_LT_NG | -19322.83883 | 11482.8953 |  | rpm
Air | Dens | 1.225 | kg/m^3 | SLS Std Day |  |  |  | 25 | 38.5 | 0.287 |  |  |  |  | P_NG_NT | -5799.543768 | 0.9769 |  | rpm
 |  |  |  |  |  |  |  | 16 | 29.3 | 0.442 |  |  |  |  | P_NT_NG | 5950.435046 | 1.0229 |  | rpm
Thtl | min | 0 | V Pot |  |  |  |  | 12.6 | 25.8 | 0.5 |  |  |  |  | DCPDL | -0.830 |  |  | none
 | max | 5 | V Pot |  |  |  |  |  |  |  |  |  |  |  | LAMBDA | 3.16 |  |  | none
 | min | 0 | deg Throttle |  |  |  |  |  |  |  |  |  |  |  | DELTAV | 2 |  |  | m/s
 | max | 180 | deg Throttle |  |  |  |  | P_NG_QG | -0.002282899263 | 1.97751564e-07 | 9.326941385e-12 | ft-lbf |  |  |  |  |  |  | 12.59
Adjust | 1.25 | for 100% Ng at |  | 240 | watts |  |  | matlabTuning.xlsx |  |  |  | tldF=.15, tlgF=.03
 |  |  |  |  |  |  |  | TauT Design, s | Nt, % | TLD_S | LG_S | TLD_L | LG_L |  | xAll | 0.0 | 21.7 | 37.3 | 50.5 | 64.1 | 80.0
 |  |  |  |  |  |  |  | 0 | 68.3 | 0.2 | 4.4 | 0.09 | 5 |  | TLD_S | 0.475 | 0.475 | 0.325 | 0.225 | 0.200 | 0.200 | Scheduled
 |  |  |  |  |  |  |  | 0.02 | 64.1 | 0.2 | 3.75 | 0.09 | 5 |  | LG_S | 2.40 | 2.40 | 2.70 | 3.20 | 3.75 | 4.40
 |  |  |  |  |  |  |  | 0.085 | 50.5 | 0.225 | 3.2 | 0.125 | 4.050 |  | tldF | 0.15
 |  |  |  |  |  |  |  | 0.185 | 37.3 | 0.325 | 2.7 | 0.24 | 3.75 |  | tlgF | 0.03
 |  |  |  |  |  |  |  | 0.344 | 21.7 | 0.475 | 2.4 | 0.42 | 3.6 |  | TLD_L | 0.420 | 0.420 | 0.240 | 0.125 | 0.090 | 0.090 | Fixed lead
 |  |  |  |  |  |  |  | 0.5 | 12.6 | 0.475 | 2.4 | 0.42 | 3.6 |  | LG_L | 3.60 | 3.60 | 3.75 | 4.05 | 5.00 | 5.00
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

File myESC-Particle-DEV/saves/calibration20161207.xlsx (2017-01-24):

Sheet: Ard0_Turn0_ESC0_G0b_T0a
Description | Set Nt | TTL, ms | throttleFlt, deg | v4, vdc | Charger V, vdc | Charger I, A | Tng, micros | Ttur, micros |  | Charger Pwr, W | Throttle, deg | ln(Throttle) | FreqNg, Hz | FreqTur, Hz | Ng, RPM | Nt, RPM | Ng, % | Nt, % | Throttle, deg | Charger Pwr, W | Ng Pwr, W | Ng Pwr, SHP | Ng Total Torque, ft-lbf | Ng Torque, ft-lbf | Thrust, N | Thrust Power, W | Overall Efficiency | Vw, m/s | Vw, mph | Vt, m/s | Lambda tip speed ratio | dCpdLambda | simulate vpot from throttle | model throttle from vpot | Model Ng from Model Throttle, rpm | Model Ng from Model Throttle, % | Model pcntRef from Model Ng, % | Model Ng from pcntRef at RESET, % | Model Nt from Model Ng, % | Model Nt from Model Ng, rpm | Model Qg from Model Ng, ft-lbf | Model PwrG from Model Ng*Q, shp | Model dQgdNg, ft-lbf/rpm | Model TauG | Model dQtdNt, ft-lbf/rpm | Model TauT from wind | v4, vdc
DC Power Overhead | n/a | 1.03 | 6.07 | 0.0032 | 12.24 | 0.019 | 1e+32 | 1e+32 |  | 0.2 | 6.07 | 1.8027 | 1e-26 | 1e-26 | 6e-25 | 0 | 1.302083333e-27 | 0 | 6.066122035 | 0.23 | 0 | 0.0000 | 0.00000 | 0.00000 | 7.502157933e-58 | 2.015459293e-85 |  | 5.373012168e-28 | 1.208927738e-27 | 0 | 0.00 |  | 0.169 | 6.066 | 0.00 | 0.00 | -17.48 | 0.03 |  | 0 |  |  |  |  |  |  | 0.0032
Lowest Ng | n/a | 1.05 | 9 | 0.0024 | 12.15 | 0.34 | 7080 | 1e+32 |  | 4.1 | 9 | 2.1972 | 141.2429379 | 1e-26 | 8474.576271 | 6e-25 | 18.39100753 | 1.302083333e-27 | 9 | 4.07 | 3.83769 | 0.0051 | 0.00319 | 0.00000 | 0.150 | 0.57 | 14.0 | 7.59 | 17.1 | 1.727875959e-27 | 2.27681632e-28 |  | 0.250 | 9.000 | 4918.12 | 10.67 | -7.36 | 10.70 |  | 0 | 0.00000 | 0.00000 | 1.105647023e-07 |  |  |  | 0.0024
First Nt | tbd | 1.11 | 20 | 0.069 | 12.14 | 0.86 | 4040 | 68000 |  | 10.5 | 20 | 2.9957 | 247.5247525 | 14.70588235 | 14851.48515 | 882.3529412 | 32.22978548 | 1.914828431 | 20 | 10.45 | 10.22 | 0.0137 | 0.00485 | 0.00166 | 0.460 | 3.06 | 29.2 | 13.30 | 29.9 | 2.5 | 0.19 |  | 0.556 | 20.000 | 14872.75 | 32.28 | 13.10 | 32.29 | 13.1 | 6038.54 | 0.00194 | 0.00548 | 3.729326807e-07 | 0.100 |  |  | 0.069
Dynamic Nt #1 | 16 | 1.14 | 25 | 0.51 | 12.14 | 1.13 | 3680 | 8500 |  | 13.7 | 25 | 3.2189 | 271.7391304 | 117.6470588 | 16304.34783 | 7058.823529 | 35.38269928 | 15.31862745 | 25 | 13.72 | 13.49 | 0.0181 | 0.00583 | 0.00264 | 0.554 | 4.04 | 29.5 | 14.60 | 32.9 | 20.3 | 1.39 |  | 0.694 | 25.000 | 17654.58 | 38.31 | 18.82 | 38.33 | 18.8 | 8674.185965 | 0.00308 | 0.01034 | 4.462516013e-07 | 0.084 | -1.616712235e-07 | 0.231 | 0.51
Dynamic Nt #2 | 20 | 1.19 | 35 | 0.801 | 12.11 | 1.838 | 2980 | 5420 |  | 22.3 | 35 | 3.5553 | 335.5704698 | 184.501845 | 20134.22819 | 11070.1107 | 43.69407159 | 24.02367774 | 35 | 22.26 | 22.03 | 0.0295 | 0.00770 | 0.00452 | 0.845 | 7.62 | 34.2 | 18.03 | 40.6 | 31.9 | 1.77 |  | 0.972 | 35.000 | 21849.23 | 47.42 | 27.45 | 47.43 | 27.4 | 12648.40654 | 0.00518 | 0.02155 | 5.568072553e-07 | 0.067 | -2.056754194e-07 | 0.182 | 0.801
Dynamic Nt #3 | 25 | 1.30 | 54 | 1.167 | 12.06 | 3.18 | 2390 | 3740 |  | 38.4 | 54 | 3.9890 | 418.4100418 | 267.3796791 | 25104.60251 | 16042.78075 | 54.4804742 | 34.81506239 | 54 | 38.35 | 38.12 | 0.0511 | 0.01069 | 0.00750 | 1.313 | 14.76 | 38.5 | 22.48 | 50.6 | 46.2 | 2.06 |  | 1.500 | 54.000 | 27255.18 | 59.15 | 38.56 | 59.15 | 38.6 | 17770.27059 | 0.00857 | 0.04450 | 6.992882824e-07 | 0.054 | -2.627835546e-07 | 0.142 | 1.167
Dynamic Nt #4 | 36 | 1.36 | 64 | 1.275 | 12.03 | 3.96 | 2170 | 3260 |  | 47.6 | 64 | 4.1589 | 460.8294931 | 306.7484663 | 27649.76959 | 18404.90798 | 60.00384025 | 39.94120654 | 64 | 47.64 | 47.41 | 0.0636 | 0.01208 | 0.00889 | 1.593 | 19.72 | 41.4 | 24.76 | 55.7 | 53.0 | 2.14 |  | 1.778 | 64.000 | 29373.23 | 63.74 | 42.92 | 63.75 | 42.9 | 19777.02234 | 0.01011 | 0.05657 | 7.551124993e-07 | 0.050 | -2.920267737e-07 | 0.128 | 1.275
Dynamic Nt #5 | 45 | 1.50 | 90 | 1.597 | 11.95 | 5.94 | 1860 | 2690 |  | 71.0 | 90 | 4.4998 | 537.6344086 | 371.7472119 | 32258.06452 | 22304.83271 | 70.00448029 | 48.40458488 | 90 | 70.98 | 70.75 | 0.0949 | 0.01545 | 0.01226 | 2.169 | 31.32 | 44.1 | 28.89 | 65.0 | 64.2 | 2.224 |  | 2.500 | 90.000 | 33623.41 | 72.97 | 51.66 | 72.97 | 51.7 | 23803.85519 | 0.01356 | 0.08682 | 8.67131732e-07 | 0.043 | -3.449747235e-07 | 0.108 | 1.597
Dynamic Nt #6 | 50 | 1.69 | 125 | 1.95 | 11.84 | 8.59 | 1620 | 2210 |  | 101.7 | 125 | 4.8283 | 617.2839506 | 452.4886878 | 37037.03704 | 27149.32127 | 80.3755144 | 58.91779789 | 125 | 101.71 | 101.47 | 0.1361 | 0.01930 | 0.01611 | 2.859 | 47.41 | 46.6 | 33.17 | 74.6 | 78.2 | 2.357 |  | 3.472 | 125.000 | 37718.72 | 81.85 | 60.08 | 81.85 | 60.1 | 27683.96023 | 0.01733 | 0.12449 | 9.750692614e-07 | 0.038 | -3.998837084e-07 | 0.094 | 1.95
Dynamic Nt #7 | 52 | 1.86 | 155 | 2.26 | 11.66 | 12.52 | 1430 | 1900 |  | 146.0 | 155 | 5.0434 | 699.3006993 | 526.3157895 | 41958.04196 | 31578.94737 | 91.05477855 | 68.53070175 | 155 | 145.98 | 145.75 | 0.1955 | 0.02447 | 0.02128 | 3.669 | 68.92 | 47.2 | 37.57 | 84.5 | 90.9 | 2.420 | -0.409 | 4.306 | 155.000 | 40400.42 | 87.67 | 65.59 | 87.67 | 65.6 | 30224.73471 | 0.02004 | 0.15419 | 1.045749028e-06 | 0.036 | -4.564246037e-07 | 0.082 | 2.26
Dynamic Nt #7 | 52 | 1.92 | 165 | 2.34 | 11.56 | 14.28 | 1380 | 1815 |  | 165.1 | 165 | 5.1059 | 724.6376812 | 550.9641873 | 43478.26087 | 33057.85124 | 94.35386473 | 71.74012856 | 165 | 165.08 | 164.84 | 0.2211 | 0.02670 | 0.02351 | 3.939 | 76.69 | 46.5 | 38.93 | 87.6 | 95.2 | 2.445 | -0.398 | 4.583 | 165.000 | 41179.84 | 89.37 | 67.19 | 89.36 | 67.2 | 30963.18996 | 0.02087 | 0.16361 | 1.066291522e-06 | 0.035 | -4.738914707e-07 | 0.079 | 2.34
Max | tbd | 2.00 | 180 | 2.4 | 11.53 | 14.92 | 1368 | 1790 |  | 172.0 | 180 | 5.1930 | 730.994152 | 558.6592179 | 43859.64912 | 33519.55307 | 95.18153021 | 72.74208566 | 180 | 172.03 | 171.80 | 0.2304 | 0.02759 | 0.02440 | 4.425 | 91.30 | 53.1 | 41.26 | 92.8 | 96.5 | 2.339 |  | 5.000 | 180.000 | 42264.57 | 91.72 | 69.42 | 91.71 | 69.4 | 31990.91934 | 0.02204 | 0.17736 | 1.094881102e-06 | 0.034 | -5.03784686e-07 | 0.074 | 2.4
Calibration sheet
1 |  | Calibrate the ESC first |  |  |  |  |  | Key | User Inputs
2 |  | Update the Arduino software |  |  |  |  |  |  | Derived
3 |  | Run the points below |  |  |  |  |  |  | Entry to myCLAW.h and potESC.ino
4 |  | Enter blue highlighted items into myCLaw.h |  |  |  |  |  |  | Entry to myCLAW.h and potESC.ino; same between units
5 |  | Run the frequency response fr_
6 |  | Enter results of fr_ into table lower right corner this sheet
7 |  | Hand tune DELTAV |  |  |  |  |  |  |  |  |  |  |  |  | // Constants always defined - potESC.ino #ifdef Arduino
8 |  | Check that Nt corresponding to entry in column AG lines up with Nt from Z in Tau data |  |  |  |  |  |  |  |  |  |  |  |  | POT_MAX | 5 |  |  | v
 |  |  |  |  |  |  |  |  |  |  |  |  |  |  | F2V_MAX | 5 |  |  | v
Motor | numPoles | 1 |  |  |  |  |  | Inertia Turbine Only (need motor***) |  |  |  |  |  |  | F2V_MIN | 0 |  |  | v
 | Kv | 4800 | rpm/V |  |  |  |  | Rt= | 25 | mm |  |  |  |  | POT_MIN | 0 |  |  | v
 | Vc | 12 |  |  |  |  |  | Mt= | 2.1797 | gm |  |  |  |  | DENS_SI | 1.225 |  |  | kg/m^3
 | Ra | 0.0399 | O |  |  |  |  | Jt= | 0.001548498305 | lbm-in^2 | 1/3*MR^2
 | La | 4.2e-06 | H |  |  |  |  | Rm= | 4.8 | mm | at most |  |  |  | // See calibration<date>.xlsx - myCLAW.h
 | Power | 240 | W max |  |  |  |  | Lm= | 19.0 | mm | at most |  |  |  | RPM_P | 460.8 |  |  | rpm/%
 | Kvrps | 502.7 | r/s / V |  |  |  |  | Mm= | 0.006212622191 | lbm | at most |  |  |  | THTL_MAX | 180 |  |  | deg
 | Kt | 0.0139 | ft-lbf/A |  |  |  |  | Jm | 0.0001092062495 | lbm-in^2 | 1/2*MR^2 |  |  |  | THTL_MIN | 0 |  |  | deg
 | Fn | 0.99 | lbf |  |  |  |  | J= | 0.001657704555 | lbm-in^2 |  |  |  |  | AREA_SI | 0.002121360439 |  |  | m^2
 |  |  |  |  |  |  |  | J= | 1.151183719e-05 | lbm-ft^2 |  |  |  |  | NM_2_FTLBF | 0.738 |  |  | ft-lbf/N-m
LM2907N Circuit |  | vf2v, v |  |  |  |  |  | J= | 3.74268175e-08 | ft-lbf/(rpm/sec) |  |  |  |  | JT | 3.74268175e-08 |  |  | rpm/s / ft-lbf
 | F2V_MIN | 0 |  |  |  |  |  |  |  |  |  |  |  |  | D_SI | 0.055 |  |  | m
 | F2V_MAX | 5 |  |  |  | TBD |  | From fr_a0_t0_e0_g0b_t0a.xlsx |  |  |  |  |  |  | FG_SI | 4.425 |  |  | N
 |  |  |  |  |  |  |  | Nt, % | Calc Ng, % | log(Ng) | Meas TauT0, s | Meas QdN, ft-lbf/rpm | Meas dQdN, N-m/rpm
Fan Rotor | Dia | 55 | mm |  |  |  |  | 83.9 | 107.0 | 2.029 | 0 |  |  |  | // Ard0_Turn0_ESC0_G0b_T0a - myCLAW.h
 | Dia spinner | 18 | mm |  |  |  |  | 62 | 83.9 | 1.924 | 0.050 |  |  |  | P_V4_NT | 0 | 13956.20615 | 25.15526562 | rpm
 |  |  |  |  |  |  |  | 48 | 69.1 | 1.840 | 0.082 | 4.564246037e-07 | -6.187291928e-07 |  | P_LT_NG | -22473.69517 | 12466.55113 |  | rpm
Air | Dens | 1.225 | kg/m^3 | SLS Std Day |  |  |  | 25 | 44.8 | 1.652 | 0.196 |  |  |  | P_NG_NT | -8052.654718 | 0.9475 |  | rpm
 |  |  |  |  |  |  |  | 16 | 35.3 | 1.548 | 0.249 |  |  |  | P_NT_NG | 8510.224957 | 1.0550 |  | rpm
Thtl | min | 0 | V Pot |  |  |  |  | -26.6 | -9.6 |  | 0.5 |  |  |  | DCPDL | -0.409 |  |  | none
 | max | 5 | V Pot |  |  |  |  |  |  |  |  |  |  |  | LAMBDA | 2.42 |  |  | none
 | min | 0 | deg Throttle |  |  |  |  |  |  |  |  |  |  |  | DELTAV | 2 |  |  | m/s
 | max | 180 | deg Throttle |  |  |  |  | P_NG_QG | -0.000695441078 | -1.905896073e-08 | 1.317817906e-11 | ft-lbf
Adjust | 1.25 | for 100% Ng at |  | 240 | watts |  |  | matlabTuning.xlsx |  |  |  | tldF=.15, tlgF=.03
 |  |  |  |  |  |  |  | TauT Design, s | Nt, % | TLD_S | LG_S | TLD_L | LG_L |  | xAll | 0.0 | -0.1 | 27.2 | 47.4 | 75.1 | 80.0
 |  |  |  |  |  |  |  | 0 | 83.9 | 0.2 | 4.4 | 0.09 | 5 |  | TLD_S | 0.475 | 0.475 | 0.325 | 0.225 | 0.200 | 0.200 | Scheduled
 |  |  |  |  |  |  |  | 0.02 | 75.1 | 0.2 | 3.75 | 0.09 | 5 |  | LG_S | 2.40 | 2.40 | 2.70 | 3.20 | 3.75 | 4.40
 |  |  |  |  |  |  |  | 0.085 | 47.4 | 0.225 | 3.2 | 0.125 | 4.050 |  | tldF | 0.15
 |  |  |  |  |  |  |  | 0.185 | 27.2 | 0.325 | 2.7 | 0.24 | 3.75 |  | tlgF | 0.03
 |  |  |  |  |  |  |  | 0.344 | -0.1 | 0.475 | 2.4 | 0.42 | 3.6 |  | TLD_L | 0.420 | 0.420 | 0.240 | 0.125 | 0.090 | 0.090 | Fixed lead
 |  |  |  |  |  |  |  | 0.5 | -26.6 | 0.475 | 2.4 | 0.42 | 3.6 |  | LG_L | 3.60 | 3.60 | 3.75 | 4.05 | 5.00 | 5.00

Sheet: Ard1_Turn1x_ESC1_G1b_T1a
Description | Set Nt | TTL, ms | throttleFlt, deg | v4, vdc | Charger V, vdc | Charger I, A | Tng, micros | Ttur, micros |  | Charger Pwr, W | Throttle, deg | ln(Throttle) | FreqNg, Hz | FreqTur, Hz | Ng, RPM | Nt, RPM | Ng, % | Nt, % | Throttle, deg | Charger Pwr, W | Ng Pwr, W | Ng Pwr, SHP | Ng Total Torque, ft-lbf | Ng Torque, ft-lbf | Thrust, N | Thrust Power, W | Overall Efficiency | Vw, m/s | Vw, mph | Vt, m/s | Lambda tip speed ratio | dCpdLambda | simulate vpot from throttle | model throttle from vpot | Model Ng from Model Throttle, rpm | Model Ng from Model Throttle, % | Model pcntRef from Model Ng, % | Model Ng from pcntRef at RESET, % | Model Nt from Model Ng, % | Model Nt from Model Ng, rpm | Model Qg from Model Ng, ft-lbf | Model PwrG from Model Ng*Q, shp | Model dQgdNg, ft-lbf/rpm | Model TauG | Model dQtdNt, ft-lbf/rpm | Model TauT from wind | v4, vdc
DC Power Overhead | n/a | 1.03 | 5.38 | 0.0032 | 12.24 | 0.019 | 1e+32 | 1e+32 |  | 0.2 | 5.38 | 1.6827 | 1e-26 | 1e-26 | 6e-25 | 0 | 1.302083333e-27 | 0 | 5.380330042 | 0.23 | 0 | 0.0000 | 0.00000 | 0.00000 | 7.502157933e-58 | 2.015459293e-85 |  | 5.373012168e-28 | 1.208927738e-27 | 0 | 0.00 |  | 0.149 | 5.380 | 0.00 | 0.00 | -12.31 | 0.05 |  | 0 |  |  |  |  |  |  | 0.0032
Lowest Ng | n/a | 1.04 | 8 | 0.0046 | 12.23 | 0.28 | 8000 | 1e+32 |  | 3.4 | 8 | 2.0794 | 125 | 1e-26 | 7500 | 6e-25 | 16.27604167 | 1.302083333e-27 | 8 | 3.39 | 3.15515 | 0.0042 | 0.00296 | 0.00000 | 0.117 | 0.39 | 11.6 | 6.72 | 15.1 | 1.727875959e-27 | -6.089757139e-27 |  | 0.222 | 8.000 | 4555.17 | 9.89 | -2.69 | 9.92 |  | 0 | 0.00000 | 0.00000 | 2.827231837e-07 |  |  |  | 0.0046 |  | -12.400000
First Nt | tbd | 1.07 | 12 | 0.238 | 12.25 | 0.53 | 5540 | 13200 |  | 6.5 | 12 | 2.4849 | 180.5054152 | 75.75757576 | 10830.32491 | 4545.454545 | 23.50330927 | 9.864267677 | 12 | 6.47 | 6.24 | 0.0084 | 0.00405 | 0.00109 | 0.244 | 1.19 | 18.3 | 9.70 | 21.8 | 13.1 | 4.85 |  | 0.333 | 12.000 | 9211.08 | 19.99 | 7.14 | 20.02 | 7.1 | 3291.001972 | 0.00033 | 0.00058 | 3.695740461e-07 | 0.101 |  |  | 0.238 |  | 72.50000
Dynamic Nt #1 | 16 | 1.09 | 17 | 0.434 | 12.24 | 0.655 | 4900 | 10000 |  | 8.0 | 17 | 2.8332 | 204.0816327 | 100 | 12244.89796 | 6000 | 26.57312925 | 13.02083333 | 17 | 8.02 | 7.78 | 0.0104 | 0.00448 | 0.00151 | 0.312 | 1.71 | 21.4 | 10.97 | 24.7 | 17.3 | 4.36 |  | 0.472 | 17.000 | 13210.65 | 28.67 | 15.59 | 28.69 | 15.6 | 7182.306453 | 0.00196 | 0.00492 | 4.44181543e-07 | 0.084 |  |  | 0.434
Dynamic Nt #2 | 20 | 1.12 | 21 | 0.586 | 12.24 | 0.877 | 4180 | 7500 |  | 10.7 | 21 | 3.0445 | 239.2344498 | 133.3333333 | 14354.06699 | 8000 | 31.15031898 | 17.36111111 | 21 | 10.73 | 10.50 | 0.0141 | 0.00515 | 0.00219 | 0.429 | 2.76 | 25.7 | 12.85 | 28.9 | 23.0 | 3.94 |  | 0.583 | 21.000 | 15637.09 | 33.93 | 20.71 | 33.95 | 20.7 | 9543.06505 | 0.00309 | 0.00920 | 4.89444074e-07 | 0.076 | -1.1524857e-07 | 0.325 | 0.586 | 0.44 | -8.506094887e-08
Dynamic Nt #3 | 25 | 1.15 | 27 | 0.793 | 12.23 | 1.23 | 3540 | 5580 |  | 15.0 | 27 | 3.2958 | 282.4858757 | 179.2114695 | 16949.15254 | 10752.68817 | 36.78201507 | 23.33482676 | 27 | 15.04 | 14.81 | 0.0199 | 0.00615 | 0.00319 | 0.599 | 4.54 | 30.2 | 15.18 | 34.2 | 31.0 | 3.79 |  | 0.750 | 27.000 | 18522.91 | 40.20 | 26.80 | 40.21 | 26.8 | 12350.76578 | 0.00458 | 0.01615 | 5.43275771e-07 | 0.069 | -1.609988706e-07 | 0.232 | 0.793
Dynamic Nt #4 | 36 | 1.23 | 42 | 1.175 | 12.19 | 2.41 | 2770 | 3760 |  | 29.4 | 42 | 3.7377 | 361.0108303 | 265.9574468 | 21660.64982 | 15957.44681 | 47.00661853 | 34.62987589 | 42 | 29.38 | 29.15 | 0.0391 | 0.00948 | 0.00651 | 0.978 | 9.48 | 32.3 | 19.40 | 43.6 | 46.0 | 3.71 |  | 1.167 | 42.000 | 23596.43 | 51.21 | 37.52 | 51.21 | 37.5 | 17286.94932 | 0.00758 | 0.03404 | 6.37916604e-07 | 0.059 | -2.440606473e-07 | 0.153 | 1.175 | 0.289 | -1.295045588e-07
Dynamic Nt #5 | 45 | 1.37 | 67 | 1.624 | 12.13 | 4.27 | 2170 | 2810 |  | 51.8 | 67 | 4.2047 | 460.8294931 | 355.8718861 | 27649.76959 | 21352.31317 | 60.00384025 | 46.33748517 | 67 | 51.80 | 51.56 | 0.0691 | 0.01313 | 0.01017 | 1.593 | 19.72 | 38.1 | 24.76 | 55.7 | 61.5 | 3.46 |  | 1.861 | 67.000 | 28959.21 | 62.85 | 48.84 | 62.84 | 48.8 | 22504.55991 | 0.01127 | 0.06212 | 7.379532029e-07 | 0.051 | -3.496463877e-07 | 0.107 | 1.624
Dynamic Nt #7 | 52 | 1.44 | 79 | 1.786 | 12.09 | 5.32 | 2020 | 2560 |  | 64.3 | 79 | 4.3694 | 495.049505 | 390.625 | 29702.9703 | 23437.5 | 64.45957096 | 50.86263021 | 79 | 64.32 | 64.09 | 0.0859 | 0.01520 | 0.01223 | 1.839 | 24.45 | 38.0 | 26.60 | 59.8 | 67.5 | 3.44 | -0.893 | 2.194 | 79.000 | 30851.07 | 66.95 | 52.83 | 66.94 | 52.8 | 24345.21582 | 0.01270 | 0.07457 | 7.732438699e-07 | 0.048 | -3.858434794e-07 | 0.097 | 1.786
Dynamic Nt #8 | 55 | 1.47 | 84 | 1.842 | 12.08 | 5.63 | 1970 | 2480 |  | 68.0 | 84 | 4.4308 | 507.6142132 | 403.2258065 | 30456.85279 | 24193.54839 | 66.09560068 | 52.50336022 | 84 | 68.01 | 67.78 | 0.0909 | 0.01567 | 0.01271 | 1.933 | 26.36 | 38.8 | 27.27 | 61.4 | 69.7 | 3.44 |  | 2.333 | 84.000 | 31555.77 | 68.48 | 54.32 | 68.47 | 54.3 | 25030.83358 | 0.01324 | 0.07958 | 7.863891339e-07 | 0.048 | -3.991341205e-07 | 0.094 | 1.842 | 0.085 | -4.403155001e-07
Dynamic Nt #8 | 62 | 1.67 | 121 | 2.19 | 11.97 | 8.66 | 1650 | 2040 |  | 103.7 | 121 | 4.7958 | 606.0606061 | 490.1960784 | 36363.63636 | 29411.76471 | 78.91414141 | 63.82761438 | 121 | 103.66 | 103.43 | 0.1387 | 0.02003 | 0.01707 | 2.756 | 44.87 | 43.3 | 32.56 | 73.3 | 84.7 | 3.31 |  | 3.361 | 121.000 | 35746.72 | 77.58 | 63.17 | 77.56 | 63.2 | 29108.34343 | 0.01670 | 0.11369 | 8.645667232e-07 | 0.043 | -5.032683074e-07 | 0.074 | 2.19
Max | tbd | 1.97 | 175 | 2.66 | 11.7 | 14.72 | 1360 | 1620 |  | 172.2 | 175 | 5.1648 | 735.2941176 | 617.2839506 | 44117.64706 | 37037.03704 | 95.74142157 | 80.3755144 | 175 | 172.22 | 171.99 | 0.2306 | 0.02746 | 0.02449 | 4.425 | 91.30 | 53.0 | 41.26 | 92.8 | 106.7 | 3.11 |  | 4.861 | 175.000 | 39983.86 | 86.77 | 72.12 | 86.75 | 72.1 | 33230.78376 | 0.02054 | 0.15633 | 9.436057589e-07 | 0.040 | -6.745638381e-07 | 0.055 | 2.66 | 0.035 | -1.069337643e-06
Calibration sheet
1 |  | Calibrate the ESC first |  |  |  |  |  | Key | User Inputs
2 |  | Update the Arduino software |  |  |  |  |  |  | Derived
3 |  | Run the points below |  |  |  |  |  |  | Entry to myCLAW.h and potESC.ino
4 |  | Enter blue highlighted items into myCLaw.h |  |  |  |  |  |  | Entry to myCLAW.h and potESC.ino; same between units
5 |  | Run the frequency response fr_
6 |  | Enter results of fr_ into table lower right corner this sheet
7 |  | Hand tune DELTAV |  |  |  |  |  |  |  |  |  |  |  |  | // Constants always defined - potESC.ino #ifdef Arduino
8 |  | Check that Nt corresponding to entry in column AG lines up with Nt from Z in Tau data |  |  |  |  |  |  |  |  |  |  |  |  | POT_MAX | 5 |  |  | v
 |  |  |  |  |  |  |  |  |  |  |  |  |  |  | F2V_MAX | 5 |  |  | v
Motor | numPoles | 1 |  |  |  |  |  | Inertia Turbine Only (need motor***) |  |  |  |  |  |  | F2V_MIN | 0 |  |  | v
 | Kv | 4800 | rpm/V |  |  |  |  | Rt= | 25 | mm |  |  |  |  | POT_MIN | 0 |  |  | v
 | Vc | 12 |  |  |  |  |  | Mt= | 2.1797 | gm |  |  |  |  | DENS_SI | 1.225 |  |  | kg/m^3
 | Ra | 0.0399 | O |  |  |  |  | Jt= | 0.001548498305 | lbm-in^2 | 1/3*MR^2
 | La | 4.2e-06 | H |  |  |  |  | Rm= | 4.8 | mm | at most |  |  |  | // See calibration<date>.xlsx - myCLAW.h
 | Power | 240 | W max |  |  |  |  | Lm= | 19.0 | mm | at most |  |  |  | RPM_P | 460.8 |  |  | rpm/%
 | Kvrps | 502.7 | r/s / V |  |  |  |  | Mm= | 0.006212622191 | lbm | at most |  |  |  | THTL_MAX | 180 |  |  | deg
 | Kt | 0.0139 | ft-lbf/A |  |  |  |  | Jm | 0.0001092062495 | lbm-in^2 | 1/2*MR^2 |  |  |  | THTL_MIN | 0 |  |  | deg
 | Fn | 0.99 | lbf |  |  |  |  | J= | 0.001657704555 | lbm-in^2 |  |  |  |  | AREA_SI | 0.002121360439 |  |  | m^2
 |  |  |  |  |  |  |  | J= | 1.151183719e-05 | lbm-ft^2 |  |  |  |  | NM_2_FTLBF | 0.738 |  |  | ft-lbf/N-m
LM2907N Circuit |  | vf2v, v |  |  |  |  |  | J= | 3.74268175e-08 | ft-lbf/(rpm/sec) |  |  |  |  | JT | 3.74268175e-08 |  |  | rpm/s / ft-lbf
 | F2V_MIN | 0 |  |  |  |  |  |  |  |  |  |  |  |  | D_SI | 0.055 |  |  | m
 | F2V_MAX | 5 |  |  |  |  |  | From fr_a1_t1_e1_g1b_t1a.xlsx |  |  |  |  |  |  | FG_SI | 4.425 |  |  | N
 |  |  |  |  |  |  |  | Nt, % | Calc Ng, % | log(Ng) | Meas TauT1, s | Meas QdN, ft-lbf/rpm | Meas dQdN, N-m/rpm
Fan Rotor | Dia | 55 | mm |  |  |  |  | 68.3 | 82.8 | 1.918 | 0 |  |  |  | // Ard1_Turn1x_ESC1_G1b_T1a - myCLAW.h
 | Dia spinner | 18 | mm |  |  |  |  | 62 | 76.4 | 1.883 | 0.030 |  |  |  | P_V4_NT | 0 | 12762.33491 | 354.1856204 | rpm
 |  |  |  |  |  |  |  | 48 | 62.0 | 1.792 | 0.097 | 3.858434794e-07 | -5.230494207e-07 |  | P_LT_NG | -19322.83883 | 11482.8953 |  | rpm
Air | Dens | 1.225 | kg/m^3 | SLS Std Day |  |  |  | 25 | 38.4 | 1.584 | 0.287 |  |  |  | P_NG_NT | -5670.746145 | 0.973 |  | rpm
 |  |  |  |  |  |  |  | 16 | 29.1 | 1.464 | 0.442 |  |  |  | P_NT_NG | 5845.175168 | 1.027 |  | rpm
Thtl | min | 0 | V Pot |  |  |  |  | 12.6 | 25.7 | 1.409 | 0.5 |  |  |  | DCPDL | -0.89 |  |  | none
 | max | 5 | V Pot |  |  |  |  |  |  |  |  |  |  |  | LAMBDA | 3.4 |  |  | none
 | min | 0 | deg Throttle |  |  |  |  |  |  |  |  |  |  |  | DELTAV | 7 |  |  | m/s
 | max | 180 | deg Throttle |  |  |  |  | P_NG_QG | -0.002282899263 | 1.97751564e-07 | 9.326941385e-12 | ft-lbf
Adjust | 1.25 | for 100% Ng at |  | 240 | watts |  |  | matlabTuning.xlsx |  |  |  | tldF=.15, tlgF=.03
 |  |  |  |  |  |  |  | TauT Design, s | Nt, % | TLD_S | LG_S | TLD_L | LG_L |  | xAll | 0.0 | 21.7 | 37.3 | 50.5 | 64.1 | 80.0
 |  |  |  |  |  |  |  | 0 | 68.3 | 0.2 | 4.4 | 0.09 | 5 |  | TLD_S | 0.475 | 0.475 | 0.325 | 0.225 | 0.200 | 0.200 | Scheduled
 |  |  |  |  |  |  |  | 0.02 | 64.1 | 0.2 | 3.75 | 0.09 | 5 |  | LG_S | 2.40 | 2.40 | 2.70 | 3.20 | 3.75 | 4.40
 |  |  |  |  |  |  |  | 0.085 | 50.5 | 0.225 | 3.2 | 0.125 | 4.050 |  | tldF | 0.15
 |  |  |  |  |  |  |  | 0.185 | 37.3 | 0.325 | 2.7 | 0.24 | 3.75 |  | tlgF | 0.03
 |  |  |  |  |  |  |  | 0.344 | 21.7 | 0.475 | 2.4 | 0.42 | 3.6 |  | TLD_L | 0.420 | 0.420 | 0.240 | 0.125 | 0.090 | 0.090 | Fixed lead
 |  |  |  |  |  |  |  | 0.5 | 12.6 | 0.475 | 2.4 | 0.42 | 3.6 |  | LG_L | 3.60 | 3.60 | 3.75 | 4.05 | 5.00 | 5.00
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

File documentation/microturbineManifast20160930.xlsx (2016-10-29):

Manufacturer | Description | Part No | Source | Price Ea | Qty | Total | Shipping/Tax | $199.45
Hobby King | 50mm Alloy EDF 4800 kv (3s version) | Item# 20014254188 - 2x #107000044/22947 | http://www.hobbyking.com/hobbyking/store/__22947__HobbyKing_8482_50mm_Alloy_EDF_4800kv_3s_Version_.html | $20.26 | 2 | $40.52 | $8.43 | $48.95
Turnigy | Plush 25amp Speed Controller ESC | B00URCM4QO | http://www.hobbyking.com/hobbyking/store/__68532__TURNIGY_Plush_25amp_Speed_Controller_w_BEC_AR_Warehouse_.html | $18.89 | 1 | $18.89 | $6.96 | $25.85
Arduino | Uno R3 | A000066 | https://www.amazon.com/gp/product/B006H06TVG/ref=oh_aui_detailpage_o01_s00?ie=UTF8&psc=1 | $18.59 | 1 | $18.59 | $0.00 | $18.59
BINZET | Charger AC 100-240V to DC 12V 10A |  | https://www.amazon.com/gp/product/B00PK0N14M/ref=oh_aui_detailpage_o05_s00?ie=UTF8&th=1 | $17.99 | 1 | $17.99 | $0.00 | $17.99
Elegoo | Fun Kit | LYSB01ERPEMAC-ELECTRNCS | https://www.amazon.com/gp/product/B01ERPEMAC/ref=oh_aui_detailpage_o00_s00?ie=UTF8&psc=1 | $16.86 | 1 | $16.86 | $0.00 | $16.86
Fernco | PVC Couplings 2". Drill 7/32" hole for wires | P1056-22 | http://www.homedepot.com/p/2-in-x-2-in-DWV-Flexible-PVC-Coupling-P1056-22/100096490;jsessionid=FD5ADC11436A2B9FE7E68686A5A1567B | $4.99 | 2 | $9.98 | $0.56 | $10.54
Veranda | Cellular PVC Trim, 3/4 x 2-1/2 x 8' cut to 5" | H190JWS5 | http://www.homedepot.com/p/Veranda-3-4-in-x-2-1-2-in-x-8-ft-Cellular-PVC-Trim-H190JWS5/100243235 | $9.97 | 1 | $9.97 | $0.56 | $10.53
Home Depot | Toolbox | 17331512 | http://www.homedepot.com/p/The-Home-Depot-19-in-Plastic-Tool-Box-with-Metal-Latches-and-Removable-Tool-Tray-17331512/202021300 | $8.97 | 1 | $8.97 | $0.50 | $9.47
Mouser | Mouser Shipping | --- | http://www.mouser.com | $0.00 | 1 | $0.00 | $8.00 | $8.00
BW | 20 pairs 2mm Gold Plated Bueelt Banana Plug Connectors for ESC Batter |  | https://www.amazon.com/gp/product/B00T5SW7FE/ref=oh_aui_detailpage_o08_s00?ie=UTF8&psc=1 | $6.89 | 1 | $6.89 | $0.00 | $6.89
Generic | PVC Pipe 2" Sch 40, cut to 5" | 531137 | http://www.homedepot.com/p/2-in-x-10-ft-280-PSI-Schedule-40-PVC-DWV-Plain-End-Pipe/100161954 | $6.38 | 1 | $6.38 | $0.36 | $6.74
Commercial Electric | 3-way extension plug for 115 AC | # LA-05 | http://www.homedepot.com/p/Commercial-Electric-15-Amp-Triplex-Outlet-Swivel-Tap-White-LA-05/204836952 | $4.58 | 1 | $4.58 | $0.26 | $4.84
Generic | Pencil box > 6-3/4x4-1/2x1-1/2 inside |  | https://www.amazon.com/ADVANTUS-Polypropylene-Pencil-Inches-34104/dp/B0014DZE8K?s=office-products | $3.95 | 1 | $3.95 | $0.22 | $4.17
Gardner Bender | Shrink Tubing, 5 pk 3/16" black | HST-187B | http://www.homedepot.com/p/Gardner-Bender-3-16-in-Black-Polyolefin-Heat-Shrink-Tubing-5-Pack-HST-187B/202797315 | $1.99 | 1 | $1.99 | $0.11 | $2.10
Texas Instruments | Demodulator 10 kHz, through hole | LM2907N/NOPB | http://www.mouser.com/Search/ProductDetail.aspx | $1.91 | 1 | $1.91 | $0.00 | $1.91
Alpha | Potentiometer Linear, 10K, 20%, 500V | RV24AF-22-15R1-B10K-3LA | http://www.mouser.com/Search/ProductDetail.aspx | $1.61 | 1 | $1.61 | $0.00 | $1.61
Kemet | Cap .01 uF 5% 50 VDC | SMR5103J50J01L16.5CBULK | http://www.mouser.com/Search/ProductDetail.aspx | $0.63 | 1 | $0.63 | $0.04 | $0.67
Vimex | Slide Switch SPDT, 30V 500mA | SS-12E17 | http://www.jameco.com/z/SS-12E17-3-Pin-SPDT-Slide-Switch_2258831.html | $0.49 | 1 | $0.49 | $2.13 | $2.62
Kemet | Cap 1 uF, 20 VDC, 5% | T322A105J020AS | http://www.mouser.com/Search/ProductDetail.aspx | $0.85 | 1 | $0.85 | $0.05 | $0.90
Kemet | Cap 10 uF, 25 VDC, 20% | EEA-GA1E100 | http://www.mouser.com/Search/Refine.aspx?Keyword=EEA-GA1E100 | $0.22 | 1 | $0.22 | $0.01 | $0.23
Lenovo | Thinkpad X1 Laptop, GE Provided | n/a | n/a | - | 1 | - | - | -
Arduino | Portable IDE | n/a | https://www.arduino.cc/en/Guide/PortableIDE | - | 1 | - | - | -

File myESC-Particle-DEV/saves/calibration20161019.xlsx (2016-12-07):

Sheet: Arduino1_Turnigy1_1a1ba
Description | Set Nt | TTL, ms | throttleFlt, deg | v4, vdc | Charger V, vdc | Charger I, A | Tng, micros | Ttur, micros | Vemf, V pk-pk | Charger Pwr, W | Throttle, deg | ln(Throttle) | FreqNg, Hz | FreqTur, Hz | Ng, RPM | Nt, RPM | Ng, % | Nt, % | Throttle, deg | Charger Pwr, W | Ng Pwr, W | Ng Pwr, SHP | Ng Total Torque, ft-lbf | Ng Torque, ft-lbf | Thrust, N | Power From Thrust, W | Efficiency | Vw, m/s | Vw, mph | Vt, m/s | Lambda tip speed ratio | dCpdLambda | simulate vpot from throttle | model throttle from vpot | Model Ng from Model Throttle, rpm | Model Ng from Model Throttle, % | Model pcntRef from Model Ng, % | Model Ng from pcntRef at RESET, % | Model Nt from Model Ng, % | Model Nt from Model Ng, rpm | Model Qg from Model Ng, ft-lbf | Model PwrG from Model Ng*Q, shp | Model dQgdNg, ft-lbf/rpm | Model TauG |  | Model dQtdNt, ft-lbf/rpm | Model TauT from wind |  | Model TauA | Model Inner Gain
Zero Throttle | n/a | 1.000005556 | 0.001 |  |  |  |  |  |  |  | 0.001 | -6.907755279 |  |  | 0 | 0 | 0 | 0 | 0.001 | 0 |  |  |  |  |  |  |  |  |  |  |  |  | #REF! | #REF! | #VALUE! | #VALUE! | #VALUE! | #VALUE! |  | #VALUE!
DC Power Overhead | n/a | #VALUE! | #VALUE! |  | 13.82 | 0.322 | 1e+32 | 1e+32 | 0 | 4.5 | #VALUE! | #VALUE! | 1e-26 | 1e-26 | 6e-25 | 0 | 1.302083333e-27 | 0 | #VALUE! | 4.45004 | 0 | 0 | 0.00000 | 0.00000 | #REF! | #REF! |  | #REF! | #REF! | 0 | #REF! |  | #VALUE! | #VALUE! | #VALUE! | #VALUE! | #VALUE! | #VALUE! |  | #VALUE!
Lowest Ng | n/a | 1.05 | 9 |  | 13.69 | 0.56 | 7880 | 1e+32 | 0 | 7.7 | 9 | 2.197224577 | 126.9035533 | 1e-26 | 7614.213198 | 6e-25 | 16.52390017 | 1.302083333e-27 | 9 | 7.6664 | 3.21636 | 0.00431320952 | 0.00298 | 0.00000 | #REF! | #REF! | #REF! | #REF! | #REF! | 1.727875959e-27 | #REF! |  | #REF! | #REF! | #VALUE! | #VALUE! | #VALUE! | #VALUE! |  | #VALUE! | #VALUE! | #VALUE! | #VALUE! |  |  |  |  |  | 0.000105
Just Below Nt | n/a | 1.066666667 | 12 |  | 13.68 | 0.69 | 6200 | 1e+32 | 0 | 9.4 | 12 | 2.48490665 | 161.2903226 | 1e-26 | 9677.419355 | 6e-25 | 21.00134409 | 1.302083333e-27 | 12 | 9.38 | 4.93 | 0.006617192598 | 0.00359 | 0.00062 | #REF! | #REF! | #REF! | #REF! | #REF! | 1.727875959e-27 | #REF! |  | #REF! | #REF! | #VALUE! | #VALUE! | #VALUE! | #VALUE! |  | #VALUE! | #VALUE! | #VALUE! | #VALUE! | #REF! |  |  |  |  | 0.00011 | #VALUE!
First Nt | tbd | 1.138888889 | 25 | 0.611 | 13.77 | 1.48 | 3260 | 6740 | 4.08 | 20.4 | 25 | 3.218875825 | 306.7484663 | 148.3679525 | 18404.90798 | 8902.077151 | 39.94120654 | 19.31874382 | 25 | 20.38 | 15.93 | 0.02136189041 | 0.00610 | 0.00312 | #REF! | #REF! | #REF! | #REF! | #REF! | 25.6 | #REF! |  | #REF! | #REF! | #VALUE! | #VALUE! | #VALUE! | #VALUE! | #VALUE! | #VALUE! | #VALUE! | #VALUE! | #VALUE! | #REF! |  | #REF! | #REF! |  | 0.00011 | #VALUE!
Dynamic Nt #1 | 16 | 1.194444444 | 35 | 0.986 | 13.69 | 2.19 | 2680 | 4532 | 6.04 | 30.0 | 35 | 3.555348061 | 373.1343284 | 220.6531333 | 22388.0597 | 13239.188 | 48.585199 | 28.73087673 | 35 | 29.98 | 25.53 | 0.03423771314 | 0.00803 | 0.00506 | #REF! | #REF! | #REF! | #REF! | #REF! | 38.1 | #REF! |  | #REF! | #REF! | #VALUE! | #VALUE! | #VALUE! | #VALUE! | #VALUE! | #VALUE! | #VALUE! | #VALUE! | #VALUE! | #REF! |  | #REF! | #REF! |  | 0.00011 | #VALUE!
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

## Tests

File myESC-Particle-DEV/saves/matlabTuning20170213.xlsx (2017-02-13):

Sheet: Result Summary
Answer to Question 3
Step Response Design Results
PID
 |  | compensator |  |  |  | result
Z.TauT, s | pcnt, % | LG, r/s | TLD, s | tldF, s | tlgF, s | trise95, s | tsettle2, s | Overshoot, %pt | SS Error | GM, dB | PM, deg | wp, r/s | wc, r/s | BW45, r/s
0.344 | 16 | 3.6 | 0.429 | 0.15 | 0.03 | 0.27 | <2 | 5 | 0 | 12.6 | 67.2 | 13.8 | 4.21 | 5.9
0.185 | 25 | 3.82 | 0.242 | 0.15 | 0.03 | 0.25 | <2 | 5 | 0 | 12.2 | 68.6 | 14.2 | 4.29 | 6.38
0.085 | 47 | 4.15 | 0.138 | 0.15 | 0.03 | 0.22 | <2 | 5 | 0 | 11.9 | 70.2 | 15.6 | 4.54 | 7.26
0.02 | 70 | 5.01 | 0.093 | 0.15 | 0.03 | 0.14 | <2 | 5 | 0 | 12.3 | 73.1 | 21.5 | 5.49 | 11.2
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

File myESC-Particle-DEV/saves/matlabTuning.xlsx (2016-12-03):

E.TauE=0.2, Step |  |  |  |  |  | %settle=4.9, %OS=5, %US=1
throttle, deg | pcnf, % | pcng, % | ngrpm | Z.TauT, s | trise95, s | tsettle2, s | LG, r/s | TLD, s | GM, dB | wp, r/s | PM, deg | wc, r/s | BW45, r/s | Design tld, s | Design LG, r/s
n/a | n/a | n/a | n/a | 0.350 | 0.33 | 2 | 3.44 | 0.488 | 15.3 | 14.4 | 65.4 | 4.04 | 4.8 | 0.488 | 3.44
n/a | n/a | n/a | n/a | 0.300 | 0.315 | 2 | 3.52 | 0.426 | 15.1 | 14.6 | 65.9 | 4.1 | 5 | 0.426 | 3.52
n/a | n/a | n/a | n/a | 0.200 | 0.31 | 2 | 3.53 | 0.315 |  |  |  |  |  | 0.315 | 3.53
n/a | n/a | n/a | n/a | 0.100 | 0.23 | 2 | 4.28 | 0.204 | 13.8 | 17.2 | 70 | 4.8 | 7 | 0.204 | 4.28
n/a | n/a | n/a | n/a | 0.050 | 0.17 | 2 | 4.88 | 0.160 | 13.7 | 20.8 | 72.6 | 5.4 | 9 | 0.160 | 4.88
n/a | n/a | n/a | n/a | 0.020 | 0.12 | 2 | 5.61 | 0.141 | 14.4 | 27.4 | 75.6 | 6.2 | 12.5 | 0.141 | 5.61
E.TauE=0.1, Step |  |  |  |  |  | %settle=4.9, %OS=5, %US=1
throttle, deg | pcnt, % | pcng, % | ngrpm | Z.TauT, s | trise95, s | tsettle2, s | LG, r/s | TLD, s | GM, dB | wp, r/s | PM, deg | wc, r/s | BW45, r/s | Design tld, s | Design LG, r/s | Kp | tau | tau/taut | tau*tauT
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

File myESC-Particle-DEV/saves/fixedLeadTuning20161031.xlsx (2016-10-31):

PCNF | TauF | tldF | tlgF | TLD | LG | GM, dB | r/s | PM, deg, | r/s | w45, r/s
30 | 0.271 | 0.2 | 0.03 | 0.373 | 3.6 | 15.2 | 14.6 | 65.9 | 4 | 5
40 | 0.075 | 0.2 | 0.03 | 0.18 | 4.52 | 13.7 | 18.5 | 71.1 | 5 | 7.6
50 | 0.052 | 0.2 | 0.03 | 0.161 | 4.85 | 13.7 | 20.5 | 72.4 | 5.4 | 8.7
60 | 0.044 | 0.2 | 0.03 | 0.154 | 5 | 13.7 | 21.7 | 73 | 5.52 | 9.4
70 | 0.039 | 0.2 | 0.03 | 0.151 | 5.11 | 13.8 | 22.4 | 73.4 | 5.62 | 9.9
80 | 0.036 | 0.2 | 0.03 | 0.149 | 5.57 | 13.2 | 23 | 71.7 | 6.17 | 10.6
90 | 0.034 | 0.2 | 0.03 | 0.149 | 5.23 | 13.9 | 23.4 | 73.7 | 5.71 | 10.3
PCNF | LG_S | TLD_S
0 | 3.6 | 0.373
30 | 3.6 | 0.373
40 | 4.6 | 0.18
60 | 5 | 0.155
70 | 5.1 | 0.15
90 | 5.2 | 0.145
100 | 5.2 | 0.145

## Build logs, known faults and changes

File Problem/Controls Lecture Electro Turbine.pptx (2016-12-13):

## Control of an Electrically Powered Two-Spool Turbine Device Advanced Courses in Engineering 19 Jan 2017 rev. 1

PICTURE

Former Instructors:
- Dave Gutz (rev 2017-1)

## Outline

- Description of Project
- Wind Turbine Primer
- Modeling and Linearization
- Lab

## Description of Project

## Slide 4

Regulator: Subsystem or independent device that determines and maintains the operating parameters of a system, usually within certain prescribed or preset limits.

Read more: http://www.businessdictionary.com/definition/regulator.html

Open-loop control (https://en.wikipedia.org/wiki/Open-loop_controller) can be used in systems sufficiently well-characterized as to predict what outputs will necessarily achieve the desired states. For example, the rotational velocity of an electric motor (https://en.wikipedia.org/wiki/Electric_motor) may be well enough characterized for the supplied voltage (https://en.wikipedia.org/wiki/Voltage) to make feedback unnecessary.
The drawback of open-loop control (https://en.wikipedia.org/wiki/Open-loop_controller) is that it requires perfect knowledge of the system (i.e. one knows exactly what inputs to give in order to get the desired output), and it assumes there are no disturbances to the system.

In control theory (https://en.wikipedia.org/wiki/Control_theory), a controller is a device, historically using mechanical, hydraulic, pneumatic or electronic techniques often in combination, but more recently in the form of a microprocessor or computer, which monitors and physically alters the operating conditions of a given dynamical system (https://en.wikipedia.org/wiki/Dynamical_system).[1] (https://en.wikipedia.org/wiki/Controller_(control_theory)#cite_note-The_Principal_Goal_of_Control-1) [2] (https://en.wikipedia.org/wiki/Controller_(control_theory)#cite_note-2)Typical applications of controllers are to hold settings for temperature, pressure, flow or speed.

## Wind Turbine Primer

## Wind Turbine Overview

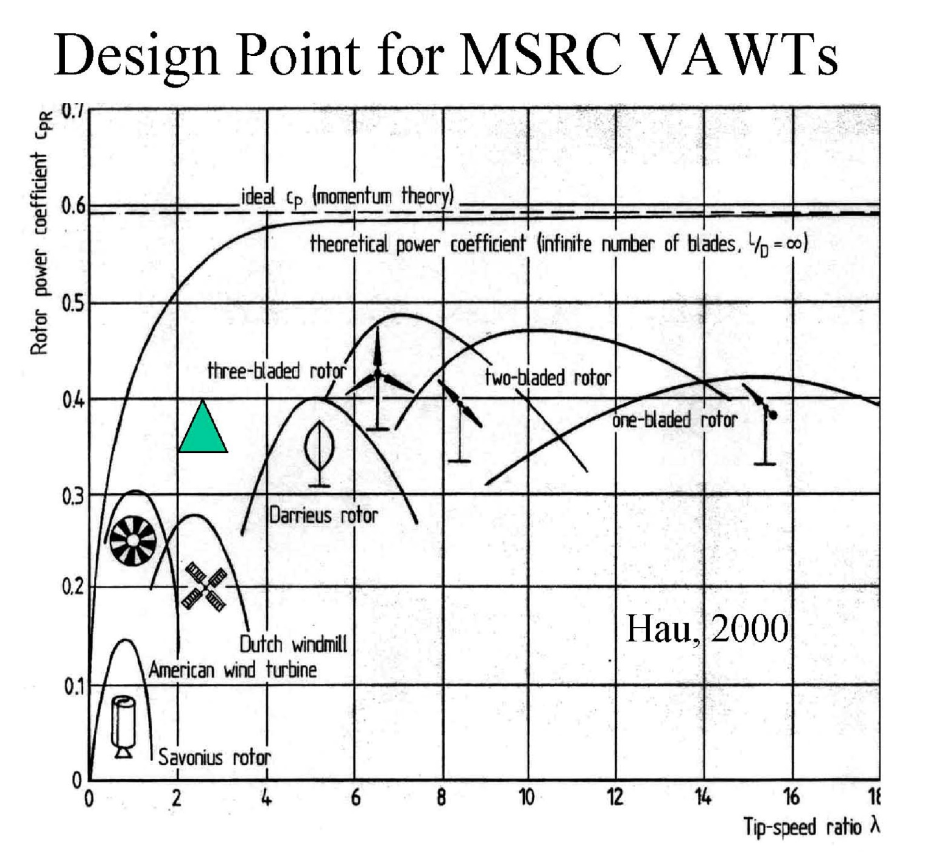
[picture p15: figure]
Image result for turbine cp curve

## Wind Turbine Primer

P_w =1/2ρAV_w ^3 , P_T =1/2C_P ρAV_w ^3 , P_T =ω_T ∙Q_T ,
where
P_w = power available in the wind, W,
P_T = power extracted by turbine, W,
V_w = wind speed, m/s,
ρ = air density, kg/m^3,
A = turbine flow area, m^2,
C_P = turbine power extraction coefficient (0-1), =(Extracted power)/(Power in wind)=(P_(rotor))/(P_(wind))
ω_T = angular speed of turbine, r/s = N_T 2π/60 , and
N_T = rotational speed of turbine, rpm.

Define another useful relationship: λ=Tip Speed Ration=TSR= (ω_(rotor) ∙R_(rotor))/(V_(wind))

http:// (http://www.nrel.gov/docs/fy12osti/52780.pdf)www.nrel.gov/docs/fy12osti/52780.pdf
Santoso,S. and Singh, M. “Dynamic Models for Wind Turbines and Wind Power Plants,” National Renewable Energy Laboratory Publication, UT Austin, Austin, Texas, NREL/SR-5500-52780 October, 2011.
https://en.wikipedia.org/wiki/Variable_speed_wind_turbine

## Speed-Speed Relationship

The project operates the turbine unloaded in a freewheeling condition at C_P =0. Here
P_(rotor) =0 and
λ= constant, where
λ = turbine tip speed ratio = V_(tip) /V_w ,
V_w = wind speed, m/s, and
V_(tip) = turbine tip speed, m/s.
The gas generator that supplies the air flow, V_w , will do so with cubic power and
square law thrust well known:
PαN_g ^3 ,
T=V_w ^2 Aρ, and
P^2 =(T^3)/(4ρA) ,
where
N_g = gas generator speed, rpm,
A = cross-sectional area of wind field, m^2,
T = air thrust with stationary gas generator fan,
ρ = air density, kg/m^3.
From this, three useful relationships emerge
V_w α N_g ,
N_T α V_w , and
N_T α N_g .

The turbine behaves like a screw in incompressible flow.

## Power Coefficient Characterized by Tip Speed Ratio

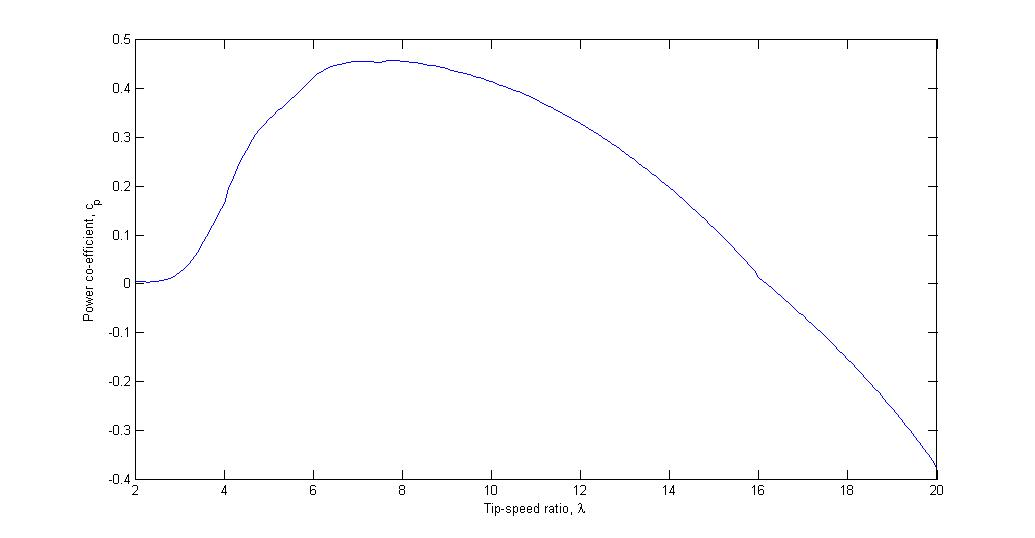
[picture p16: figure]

https://en.wikipedia.org/wiki/Variable_speed_wind_turbine

Slope is related to damping torque ( N )

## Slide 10

- Get content from my white book
- Get Cp curves from my personal OneNote
- Assumption: neglect laminar flow Re effects

## Deriving Damping from Measured Time Constant

Q_T =f(λ, C_P (λ))=g(λ)∙C_P (λ)=(ρDA)/4(V_w ^2)/λC_P (λ) ,
Where
V_w = wind speed, m/s,
ρ = air density, kg/m^3,
D = turbine tip diameter, m,
A = turbine flow area, m^2,
C_P = turbine power extraction coefficient = 0 at freewheel condition,
λ = turbine tip speed ratio = V_(tip) /V_w ,

(dQ_T)/(dN_T)=(dQ_T)/(dλ)(dλ)/(dN_T)=(δC_P (λ))/(δλ)(ρDAV_w ^2)/(4λ)(πD)/(60V_w)

(dQ_T)/(dλ)=(δg)/(δλ)C_P (λ)+(δC_P (λ))/(δλ)g(λ) , chain rule

(δλ)/(δN_T)=(πD)/(60V_w)

(δC_P (λ))/(δλ)=((dQ_T)/(dN_T)]_(meas))/((ρDAV_w ^2)/(4λ)(πD)/(60V_w))

(δg)/(δλ)=−(ρDA)/4(V_w ^2)/(λ^2)

(δC_P (λ))/(δλ)=TBD from test measurement for time constant.

## Measuring Damping to Calibrate the Model

τ=J/(dQ_T)/(dN_T) ,
where
τ = torsional time constant of air-damped turbine inertia, s,
and
J = turbine inertia, N-m/(rpm/s).
Therefore
(dQ_T)/(dN_T)]_(meas) = J/τ_(meas) .

Then, since C_P (λ) is invariant, (δC_P (λ))/(δλ) is invariant and a model equation for τ may be derived from a measurement at one operating condition. In reality, it is necessary to verify this model so multiple measurements should be made and a regression fit performed for the best result.

## Summary of Turbine Dynamic Model

In summary:
τ=J/((δC_P (λ))/(δλ)]_(meas) (ρDAV_w ^2)/(4λ)(πD)/(60V_w)) , where
V_w = wind speed, m/s, estimated from V_w α N_g using device ratings.
ρ = air density, kg/m^3,
D = turbine tip diameter, m,
A = turbine flow area, m^2,
(δC_P (λ))/(δλ) = constant measured as described earlier
λ = turbine tip speed ratio = (V_(tip))/(V_w) =constant.

## Practical Implementation of Turbine Dynamic Model

The turbine does not move until friction is overcome. This shifts the relationship between speed/airflow and time constant.
The shift may be approximated by
V_w = V_w - V_0 , where
V_0 = wind speed where turbine breaks free, m/s. This modified wind speed is then used in the previous equation.
Alternatively, if the relationships are derived using a speed shift instead,
Either method produces approximately accurate results, since the
Neither method is perfect, so in the end, an empirical curve as a function of turbine speed is used. The primary source of variation with that empirical approach is air property which could be dealt with at some future time using corrected parameters.
τ=f(N_T )

## ESC – Electronic Speed Control of Brushless DC Motor (BLDC)

## DC Motor Dynamic Model

http://www.profjrwhite.com/system_dynamics/sdyn/s6/s6fmathm/s6fmathm.html

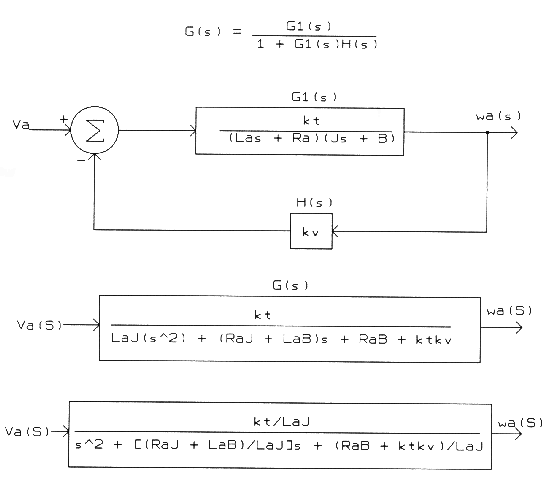
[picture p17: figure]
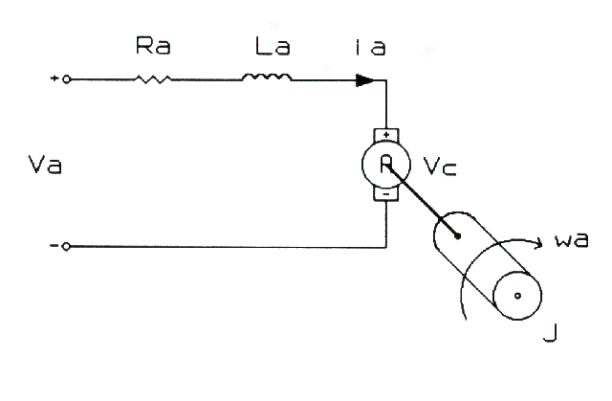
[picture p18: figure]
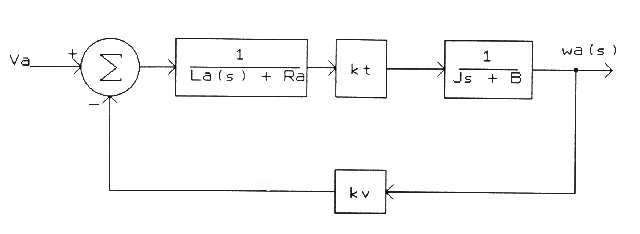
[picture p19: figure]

Bandwidth > 30 Hz

## Modeling

## Moment of Inertia of Propeller

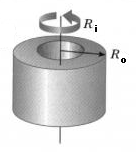
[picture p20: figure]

## Motor Constants – SI Units Assumptions

The main thing I want you to take away from this post is that when a motor rotates it generates a back-emf. That back-emf is proportional to the motor speed and the Kv constant tells you how they relate to each othe

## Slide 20

2040 Brushless Inrunner Motor 4800kv

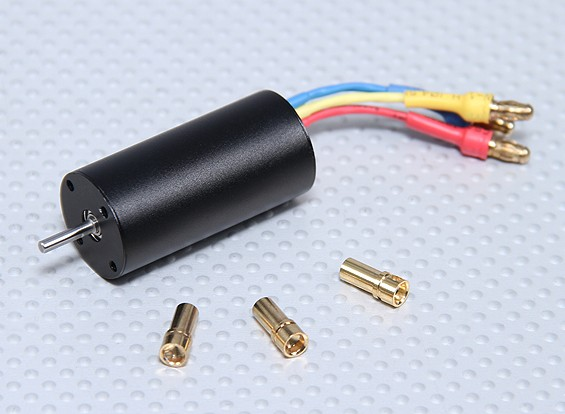
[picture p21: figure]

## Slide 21

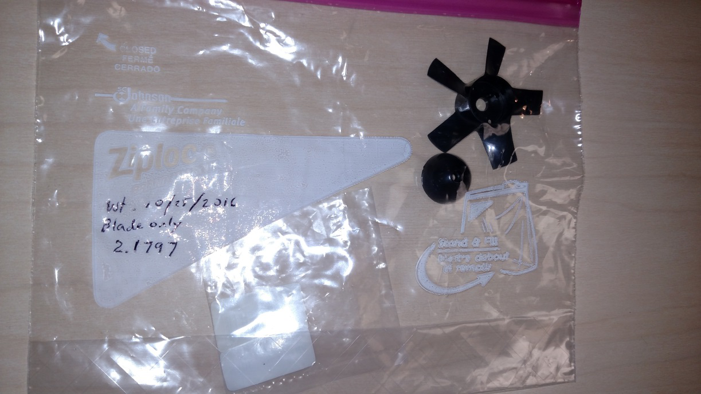
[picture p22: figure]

## Landscape of Control System Analysis

DATA Verify

Physical
System

Non-Linear Ordinary Differential Equations

- Non-linearities
- Modeline
- Toolboxes
- SISO

- Matlab Tools
- MIMO
- Linear Analysis

Linear Differential Equations

Block Diagram

State-Space

Z-Transform

Beacon

Linear
System

Simulink-Maplesim-Labview

SCADE

Embedded
Logic

Shortcut
Simulink “Linearize”

Verify

Matlab

Margin
Analysis

Academia

Control
Models

Theory

## Linearization Example – deep dive

Drop the “delta” symbols to an implied “delta model”

And apply the initial conditions at the known stability points:

## Linearization Example

Consider a simple pendulum with applied torque τ :

Physical
System

Þ

Nonlinear
Differential
Equations

Þ

Linear
Differential
Equations

τ

θ

l

M

b

The equation of motion is:

The Linear Differential Equations at two natural stability points are:

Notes: You know by inspection that the system has two equilibrium points: θ=0 and θ=π
The one at 0 is stable. The one at the top is unstable. The linearization process should reveal this.
You know by inspection that the system has two equilibrium points: θ=0 and θ=π
The one at 0 is stable. The one at the top is unstable. The linearization process should reveal this.

## Exercise #1

- Open Matlab R2013A or later
- Enter the following at the command line:
g = 32.2; % Gravity, ft/sec^2
l = g*(1/(2*pi))^2; % Pendulum length for 1 sec period, ft
b = 0.01; % Damping, lbf/(ft/sec)
d = 1; % Diameter steel pendulum sphere, in
M = 4/3*pi*(d/2)^3*.3/g; % Mass of ball, slugs
Tpulse = 1; % Pulse time, sec
Hpulse = 10; % Pulse height, ft-lbf
Dpulse = 0.1; % Pulse duration, sec
- Open a new Simulink diagram. Save it as “myPendulum.slx”
- Open “ClassroomLibrary.” If no icons appear, then make sure the “SimulinkLibrary” folder is present and try again.
- Draw the system using the blocks available in the Library
- Connect the Impulse source and scope to the system. Run it. Save it. Is the observed natural period 1 second?

## Transfer Functions

## Progress – Model to Linear D.E.

Physical
System

θ

l

M

Þ

Nonlinear
Differential
Equations

Þ

Linear
Differential
Equations

Þ

Transfer
Function

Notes: The goal is Transfer Functions

## An Aside: State Space

Recall Taylor Series Expansion of Partial Differential Equation

It is common to separate internal and external influences. This allows Eigenvalue analysis (states) separate from Boundary Value solutions.

Abbreviate

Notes: State Space is extremely useful as a bridge between different kinds of analysis tools.

## State Space Continued

Accompanying any dynamical system will be a set of O.D.E.s describing the equations of motion:

Further generalize the internal states, x. Note that ANY state has a value and a derivative. The second derivative is the derivative of the state representing the first derivative, and so on:

## State Space Continued

Now a general single-input, single-output (SISO) dynamical system will have a system of equations as it’s general representation.

Define some small letters to clean up the nomenclature:

## State Space Concluded

In general, all the parameters are vectors or arrays with all sorts of real-world cross-coupling and will be multi-input, multi-output (MIMO).

## This “State” Concept Can Be Leveraged to Create a Nice Block Diagram Connection. If this all seems a mish-mash it is. These are different symbols for representing the same concept. In fact, a Bode plot is another symbol.

## How it All Connects – these are all mathematically equivalent

ODE
Complex derivations
Math ‘engine’

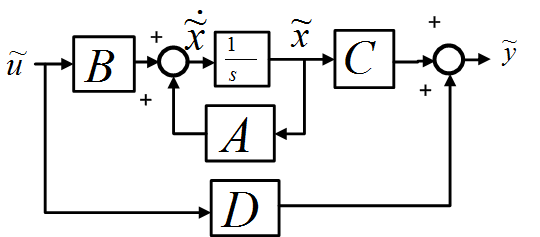
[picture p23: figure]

Physically intuitive
MIMO shorthand
GUI Application

MIMO shorthand
GUI Application
Control Intuitive (Bode bridge)
DSP connection by Fourier

## Example: Derivation of Transfer Function from Block Diagram

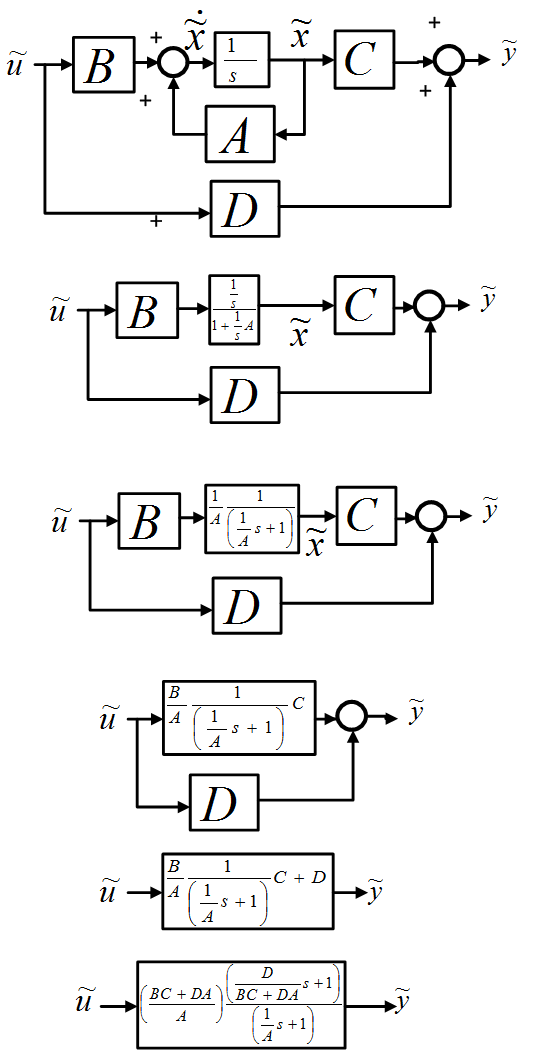
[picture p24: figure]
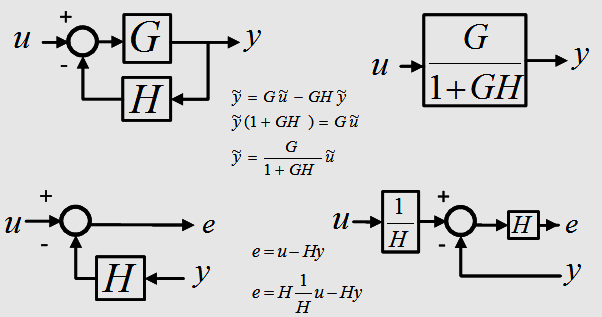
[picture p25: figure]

These are all the clues you need to know.
Block diagrams are drawings of algebraic equations.

## Example Cont’d - Transfer Function

Consider a simple pendulum with applied torque τ :

τ

θ

l

M

b

Physical
System

Þ

Nonlinear
Differential
Equations

Þ

The equation of motion is:

Linearize and apply at the bottom dead-center:

Linear
Differential
Equations

Þ

Transfer
Function

A transfer function can now be derived:

## Conclusion – Model to LTI

Physical
System

τ

θ

l

M

b

Þ

Nonlinear
Differential
Equations

Þ

Linear
Differential
Equations

Þ

Transfer
Function

Block Diagram

Þ

Þ

State-Space

Þ

Control Design

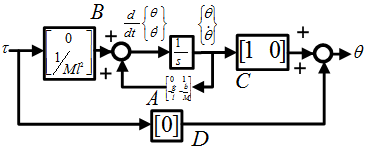
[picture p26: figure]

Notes: More on this later. Draw in Simulink now?

## In-Class Exercise:

- Draw pendulum in Simulink
- Generate time response; verify period of oscillation
- Repeat in Matlab using SS. Use CL and functions to verify Simulink result
- Repeat in Matlab using LTI.....Verify Eigenvalues. Make LTI steps and Bodes

## Frequency Response

## Types of Responses

Consider a typical second order system:

where ωn = 10 and ζ = 0.3

The following responses are presented on the next slide:

- Unforced response (with initial condition)
- Impulse response
- Step response
- Sinusoidal response

From now on we're going to concentrate on the sinusoidal or “frequency response.”

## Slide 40

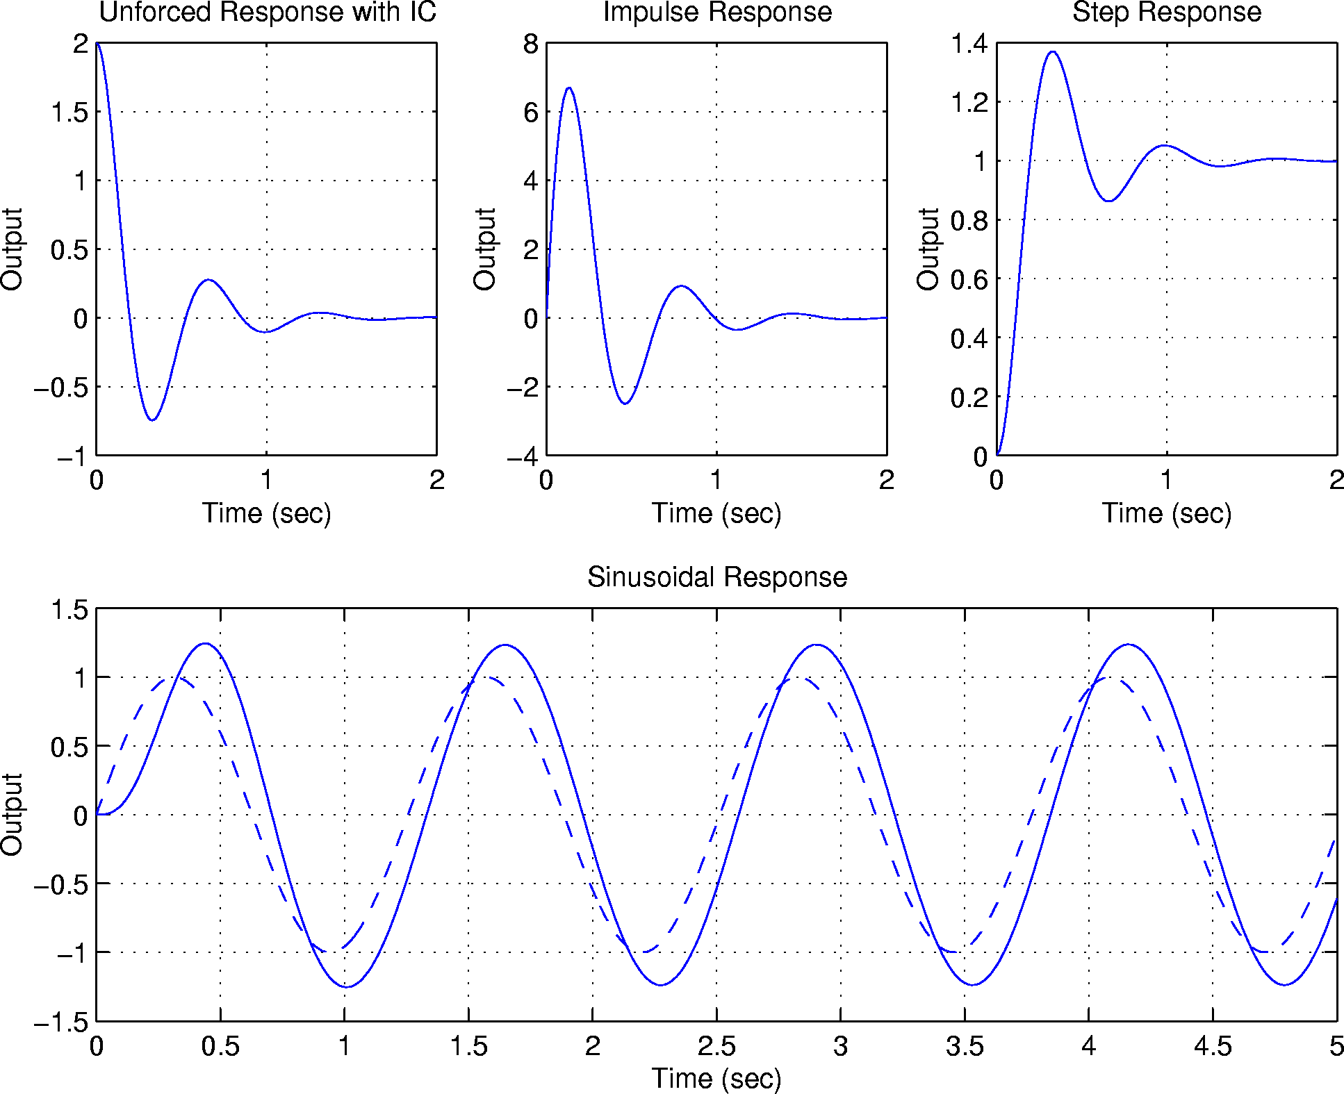
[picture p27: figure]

Do all these examples in Simulink during class. Figure out a streamlined way to do it, e.g. interactive script that pages through

## The Frequency Response

What is it?
If a stable linear time invariant system is driven with a steady sinusoidal input, the output will be another sinusoid of the same frequency but with a different amplitude and phase shift.
The frequency response of the system relates the output sinusoid
amplitude and phase shift to that of the input:

H
(LTI Sys)

In dynamic systems both the ratio B/A and the phase angle φ are functions of the frequency ω .

## What is Frequency Response (continued)

A Bode plot shows the complete picture of B/A and φ :

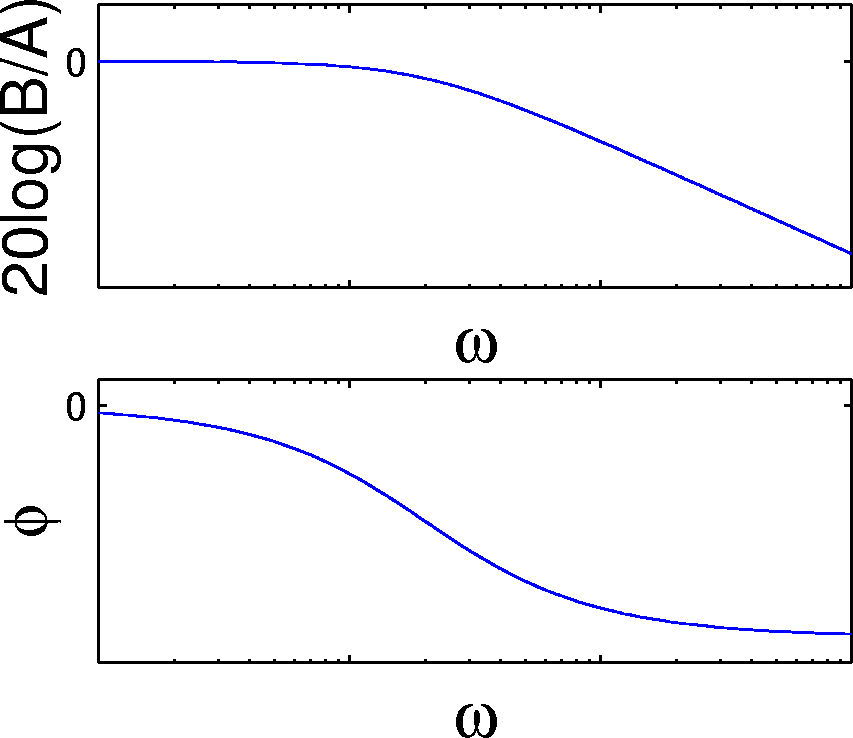
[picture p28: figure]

Note that the frequency axis is a log scale, and the magnitude is measured in decibels. This allow the response to be estimated as a series of straight lines. Also note the shape:

- Amplitude ratio rolls off as frequency increases
- Phase angle is negative

This is typical of physical systems

- They are often low pass—high frequencies are attenuated
- They exhibit phase loss or phase lag

## What is Frequency Response (continued)

Let’s look at some sinusoidal responses of

Note that as frequency gets large the output cannot keep up:

Do all these examples in Simulink during class. Figure out a streamlined way to do it, e.g. interactive script that pages through

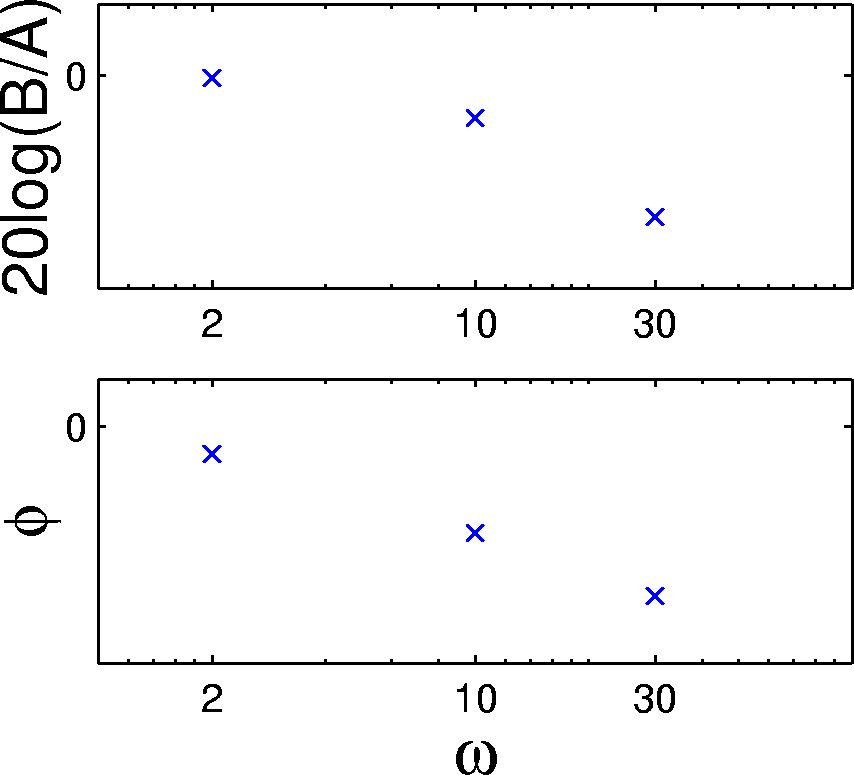
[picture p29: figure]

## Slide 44

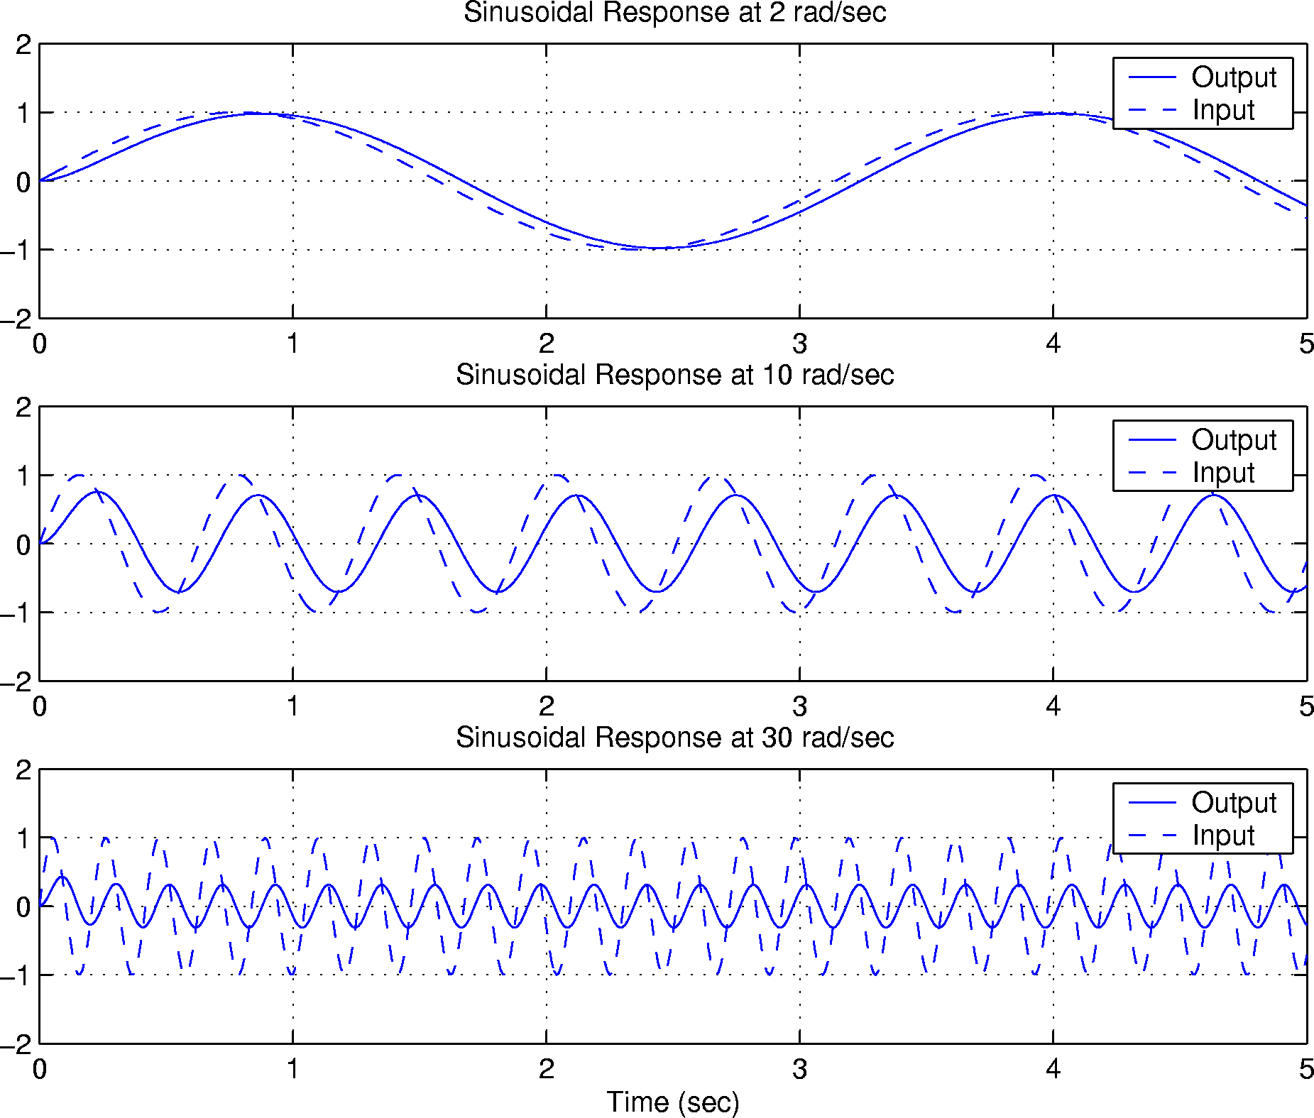
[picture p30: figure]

Do all these examples in Simulink during class. Figure out a streamlined way to do it, e.g. interactive script that pages through

## What is Frequency Response (continued)

Resonant systems have a frequency range where the output is amplified
Consider sinusoidal responses shown on the next page for

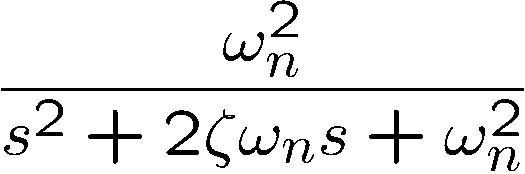
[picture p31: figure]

where ωn = 10 and ζ = 0.3

Note the amplification at ω = 10 which is at the natural frequency of the system:

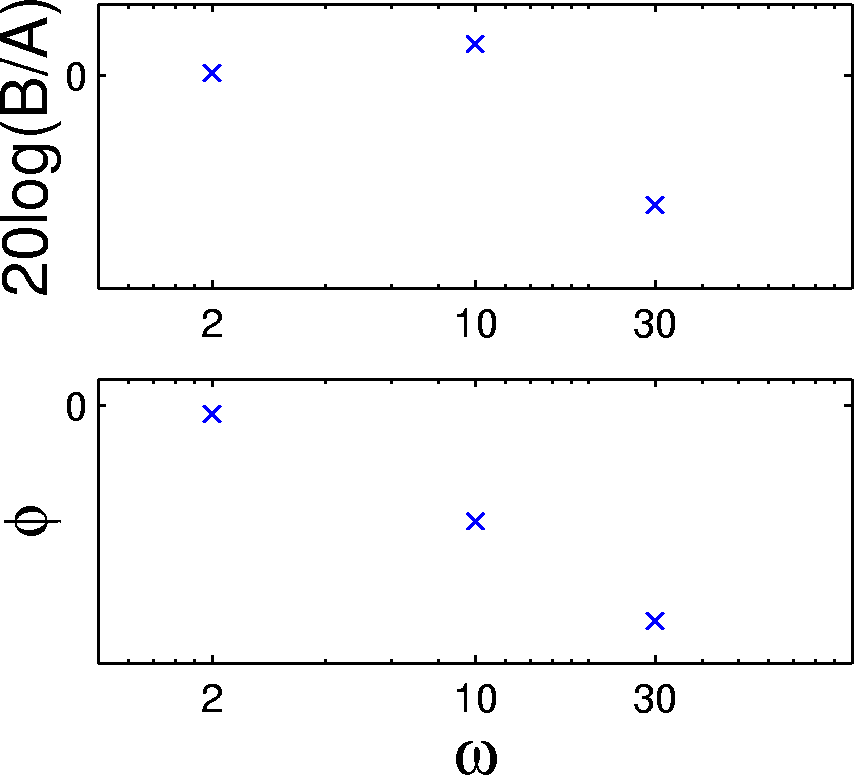
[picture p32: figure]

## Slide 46

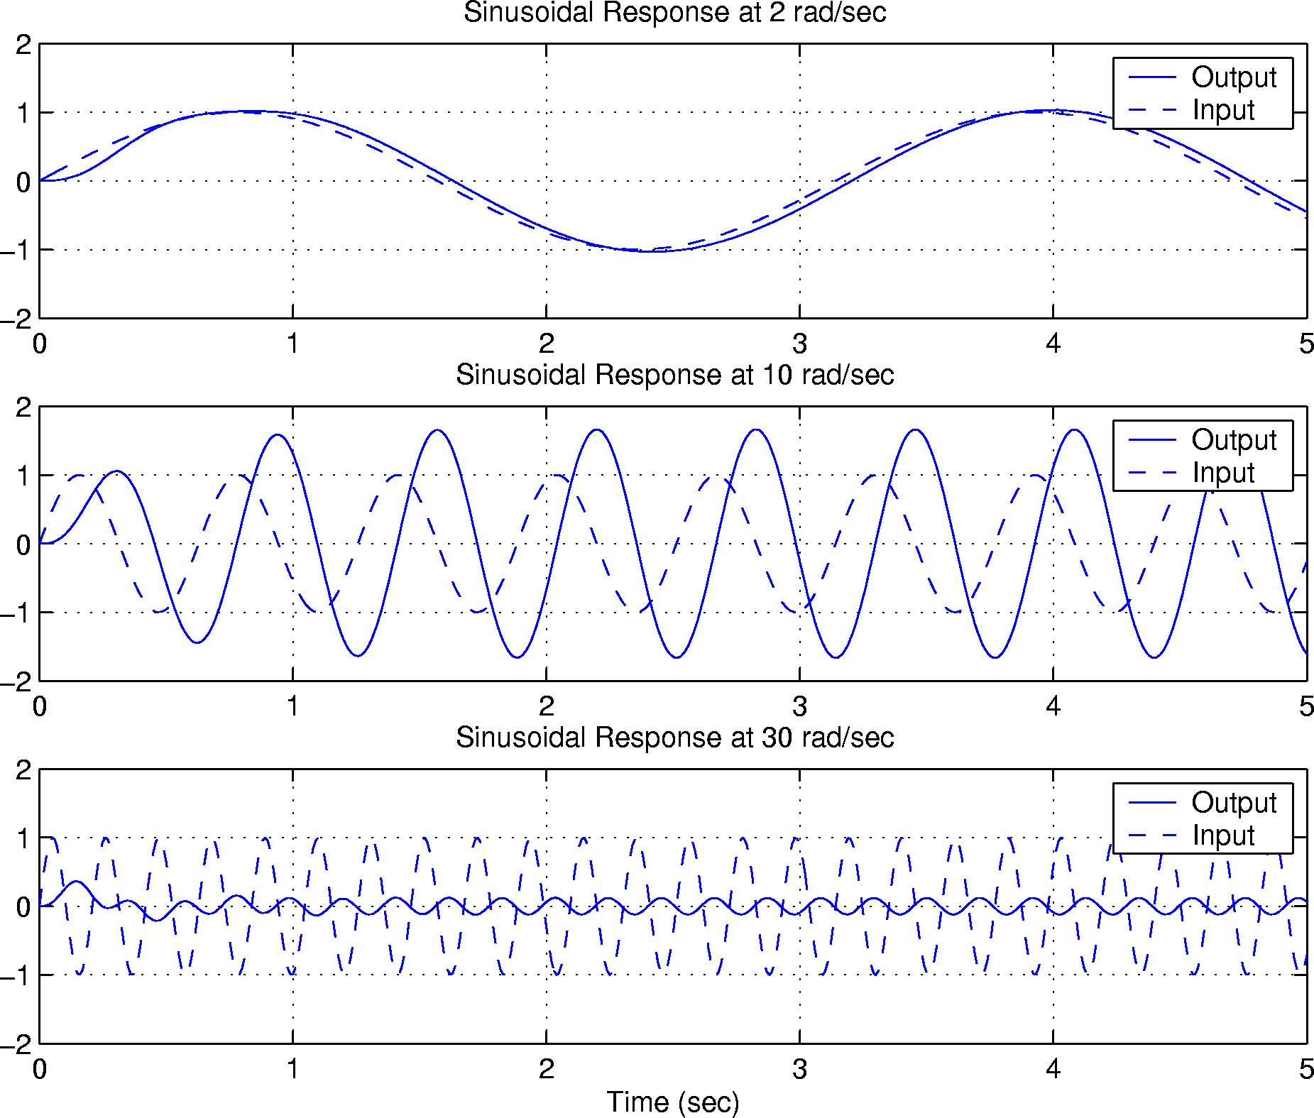
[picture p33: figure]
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

## Backup

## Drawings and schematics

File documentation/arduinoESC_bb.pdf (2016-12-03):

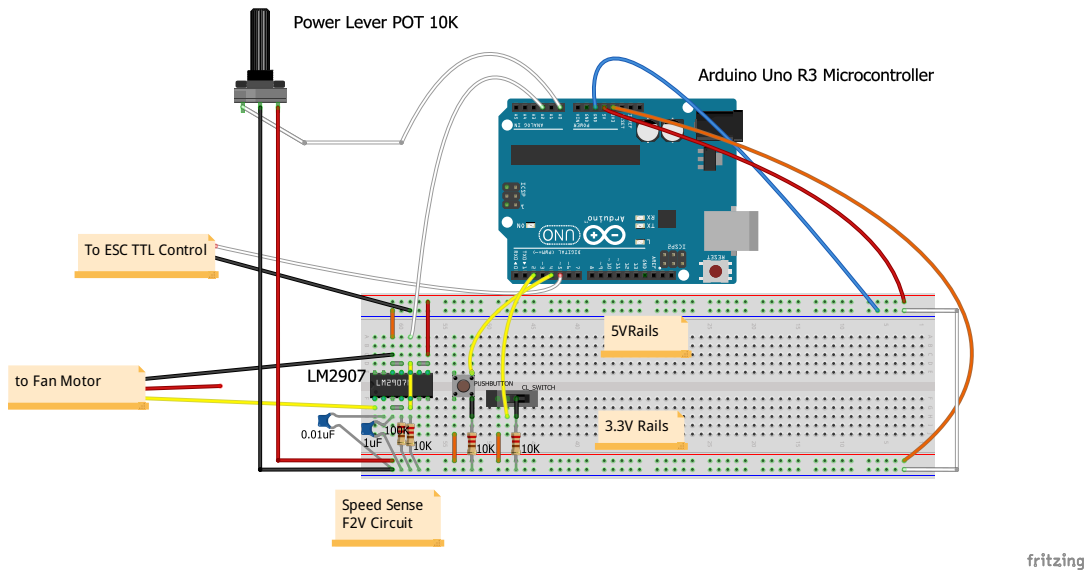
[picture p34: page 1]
3.3V Rails; 5VRails; Speed Sense F2V Circuit

To ESC TTL Control

to Fan Motor

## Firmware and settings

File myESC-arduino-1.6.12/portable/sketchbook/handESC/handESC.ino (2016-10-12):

/*
Controlling a servo position using a potentiometer (variable resistor)
by Dave Gutz

Connections for Photon:
  ESC ------------------- Photon
    BLK ------------------- GND
    WHT ------------------- PWM Output (A4)
  ESC----------------- 3-wire DC Servomotor (stepper)
    Any three to any three
  DPST switch-------------Photon
    GND-------------------D4
  DPST switch
    HI--------------------3.3V
    LO--------------------10K to GND
  F2V---------------------Photon
    V5/V10----------------Analog In A2
    GND-------------------GND
  POT---------------------Photon
    VHI ------------------3.3v
    VLO ------------------GND
    WIPE -----------------Analog In A0
  LED to indicate frequency response----Digital Output (D7)
  Hardware Platform:
    Microcontroller:  Particle Photon
    ESC:Hitec Energy Rotor 18A, 2-4S LiPo
    Power Supply:  BINZET AC 100-240V to DC 12V 10A
    Potentiometer:  Mouser 314-1410F-10K-3  10K Linear Pot
    Motor:  Hobby King 50mm Alloy EDF 4800 Kv (3s Version)
    F2V:  Texas Instruments 926-LM2907N/NOPB (14 pin, no Zener)


Connections for Arduino:
  ESC ------------------- Arduino
    BLK ------------------- GND
    WHT ------------------- PWM Output (5)
  ESC----------------- 3-wire DC Servomotor (stepper)
    Any three to any three
  F2V-----------------Arduino
    V5/V10----------------Analog In A2
    GND-------------------GND
  DPST switch-------------Arduino
    CTR-------------------4
  DPST switch
    HI--------------------3.3V
    LO--------------------10K to GND
  Push button-------------Arduino
    R---------------------2
  Push button
    HI--------------------3.3V
    LO--------------------10K to GND
  POT---------------------Arduino
    VHI ------------------5V
    VLO ------------------GND
    WIPE -----------------Analog In A0
  BUTTON ----------------Ardunio  D2
    see https://www.arduino.cc/en/Tutorial/Button
  LED to indicate frequency response----Digital Output (7)
  JUMPER---------------4 to GND for Closed Loop
  Hardware Platform:
    Microcontroller:  Arduino Uno R3
    ESC:Hitec Energy Rotor 18A, 2-4S LiPo
    Power Supply:  BINZET AC 100-240V to DC 12V 10A
    Potentiometer:  Mouser 314-1410F-10K-3  10K Linear Pot
    Motor:  Hobby King 50mm Alloy EDF 4800 Kv (3s Version)
    F2V:  Texas Instruments 926-LM2907N/NOPB (14 pin, no Zener)

  Reaquirements:
  Prime:
  1.  Manually sweep ESC command from min to max using pot.
  2.  Limit ESC command for safety using configurable parameters.
  3.  Initialize the ESC, which is built to accept min-max input on startup.
  Secondary:
  1.  USB status

  Tasks TODO:
  1.  Use the SerialEvent feature to read
      a.  f for frequency response:  freeze throttle, no rate limits, sweep, unfreeze
      b.  s for square wave response:  bias on pcnfref if closed, throttle if open
  2.  Capture closed loop frequency response, add pcnfref to array
  3.  Verify freq response again
  4.  Check against model and tune again
  5.  Mitigate integrator windup

  Revision history:
    31-Aug-2016   DA Gutz   Created
    13-Sep-2016   DA Gutz   Initial analyzing
    30-Sep-2016   DA Gutz   Arduino added

  Distributed as-is; no warranty is given.
*/


//Sometimes useful for debugging
//#pragma SPARK_NO_PREPROCESSOR
//

// Standard
#ifdef ARDUINO
  #include <Servo.h>
  #include <Print.h>
#else   // Photon
  #include "application.h"      // Should not be needed if file .ino or Arduino
  SYSTEM_THREAD(ENABLED);       // Make sure heat system code always run regardless of network status
#endif
#include "math.h"

//
// Test features usually commented
//
// Disable flags if needed.  Usually commented
// #define DISABLE
//#define BARE_PHOTON                       // Run bare photon for testing.  Bare photon without this goes dark or hangs trying to write to I2C

// Test features
extern  const int   verbose         = 2;    // Debug, as much as you can tolerate (2)

// Constants always defined
// #define CONSTANT
#ifdef ARDUINO
  #define BUTTON_PIN       2                  // Button 3-way input momentary 3.3V, steady GND (D2)
  #define PWM_PIN          5                  // PWM output (PD5)
  #define POT_PIN          A0                 // Potentiometer input pin on Arduino (PC0)
  #define CLOCK_TCK        16UL               // Clock tick resolution, micros
  #define PUBLISH_DELAY    60000UL            // Time between cloud updates (), micros
  #define CONTROL_DELAY    15000UL            // Control law wait (), micros
  #define INSCALE          1023.0             // Input full range from OS
#else   // Photon
  #define BUTTON_PIN       D2                  // Button 3-way input momentary 3.3V, steady GND (D2)
  #define PWM_PIN          A4                 // PWM output (A4)
  #define POT_PIN          A0                 // Potentiometer input pin on Photon (A0)
  #define LED_PIN          D7                 // Status LED
  #define CL_PIN           D0                 // Closed loop 3-way switch 3.3V or GND  (D0)
  #define FR_DELAY         4000000UL          // Time to start FR, micros
  #define CLOCK_TCK        8UL                // Clock tick resolution, micros
  #define PUBLISH_DELAY    40000UL            // Time between cloud updates (), micros
  #define CONTROL_DELAY    10000UL            // Control law wait (), micros
  #define INSCALE          4096.0             // Input full range from OS
#endif

//
// Dependent includes.   Easier to debug code if remove unused include files

// Global variables
char buffer[256];
Servo               myservo;  // create servo object to control a servo
double              throttleL       = 0;      // Limited servo value, 0-179 degrees
double              throttle        = -5;     // Servo value, 0-179 degrees
double              updateTime      = 0.0;    // Control law update time, sec

void setup()
{
#ifndef ARDUINO
  WiFi.disconnect();
  pinMode(LED_PIN, OUTPUT);
#endif
  pinMode(BUTTON_PIN, INPUT);
  Serial.begin(230400);
  myservo.attach(PWM_PIN);  // attaches the servo.  Only supported on pins that have PWM
  pinMode(POT_PIN, INPUT);

  delay(1000);

#ifndef ARDUINO
  WiFi.off();
#endif
  delay(100);
  sprintf(buffer, "elapsedTime,vpot,throttleU,throttle,updateTime\n");Serial.print(buffer);
}



void loop() {
#ifdef ARDUINO
  int                     buttonState = 0;    // Pushbutton
#endif
  bool                    control;            // Control sequence, T/F
  bool                    publish;            // Publish, T/F
  unsigned long           now = micros();     // Keep track of time
  static unsigned long    start        = 0UL; // Time to start looping, micros
  double                  elapsedTime;        // elapsed time, micros
  static unsigned long    lastControl  = 0UL; // Last control law time, micros
  static unsigned long    lastPublish  = 0UL; // Last publish time, micros
  static unsigned long    lastButton   = 0UL; // Last button push time, micros
  static int              RESET        = 1;   // Dynamic reset
  const  double           RESEThold    = 5;   // RESET hold, s
  // See calibration20160913.xlsx for these hardware conversion derivations
  #ifdef ARDUINO
  const double            POT_MAX      = 5.0; // Maximum POT value, vdc
  const double            POT_MIN      = 0;   // Minimum POT value, vdc
  const double            THTL_MAX     = 130;    // Maximum throttle to prevent shutdown due to small charger, deg
  const double            THTL_MIN     = 75;     // Minimum throttle, deg
  #else  // Photon
  const double            POT_MAX      = 3.3; // Maximum POT value, vdc
  const double            POT_MIN      = 0;   // Minimum POT value, vdc
  const double            THTL_MAX     = 115;    // Maximum throttle to prevent shutdown due to small charger, deg
  const double            THTL_MIN     = 60;     // Minimum throttle, deg
  #endif
////////////////////////////////////////////////////////////////////////////////////
  const double            SCMAXI       = 1*float(CONTROL_DELAY)/1000000.0;    // Maximum allowable step change reset, deg/update
  const double            SCMAX        = 240*float(CONTROL_DELAY)/1000000.0;     // Maximum allowable step change, deg/update
  static double       vpot            = 0;      // Pot value, volts
  static int          potValue        = 0;   // Dial raw value

  // Executive
  if ( start == 0UL ) start = now;
  elapsedTime  = double(now - start)*1e-6;
  publish   = ((now-lastPublish) >= PUBLISH_DELAY-CLOCK_TCK/2 );
  if ( publish )
  {
    lastPublish  = now;
  }
  unsigned long deltaT = now - lastControl;
  control = (deltaT >= CONTROL_DELAY-CLOCK_TCK/2 );
  if ( control )
  {
    lastControl   = now;
  }

  // Interrogate inputs
  if ( control )
  {
    potValue  = analogRead(POT_PIN);
    vpot      = fmin(fmax(double(potValue)/INSCALE*POT_MAX, POT_MIN), POT_MAX);
  }
  double throttleU = (vpot-POT_MIN)/(POT_MAX-POT_MIN)*(THTL_MAX-THTL_MIN)+THTL_MIN;
  // Control law
  if ( control )
  {
   // Apply rate limits as needed
    if ( RESET )
    {
      throttleL  = fmax(fmin(throttleU,   throttleL+SCMAXI),   throttleL-SCMAXI);
    }
    else
    {
      throttleL  = fmax(fmin(throttleU,   throttleL+SCMAX),   throttleL-SCMAX);
    }
    throttle  = fmin(fmax(throttleL, THTL_MIN), THTL_MAX);
}

  if ( control )
  {
    if ( elapsedTime>RESEThold ) RESET = 0;
  }


  // DAC
  if ( control  )
  {
    updateTime    = float(deltaT)/1000000.0;
    myservo.write(throttle);  // sets the servo position according to the scaled value
  }

  if ( publish )
  {
      sprintf(buffer, "%s,%s,%s,%s,%s,\n",
        String(elapsedTime,6).c_str(), String(vpot).c_str(),
        String(throttleU).c_str(), String(throttle).c_str(),
        String(updateTime,6).c_str());
      Serial.print(F(buffer));
  }  // publish
}

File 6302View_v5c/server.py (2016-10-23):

#!/usr/bin/env python

#Copyright (c) 2015,2016 Joseph D. Steinmeyer (jodalyst), Jacob White, Nick Arango
#Permission is hereby granted, free of charge, to any person obtaining a copy
#  of this software and associated documentation files (the "Software"), to deal 
#  in the Software without restriction, including without limitation the rights to use, 
#  copy, modify, merge, publish, distribute, sublicense, and/or sell copies of the 
#  Software, and to permit persons to whom the Software is furnished to do so, subject 
#  to the following conditions:

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
#Version 9 of 6.302x Software
#questions? email me at jodalyst@mit.edu
#feel free to mod this code however you want.  If you do some cool stuff, let me know...I'd like to see how far this approach can go before it hits limits


# Set this variable to "threading", "eventlet" or "gevent" to test the
# different async modes, or leave it set to None for the application to choose
# the best option based on available packages.
#async_mode = 'threading'
#async_mode = 'eventlet'
async_mode = None
if async_mode is None:
    try:
        import eventlet
        async_mode = 'eventlet'
    except ImportError:
        pass

    if async_mode is None:
        try:
            from gevent import monkey
            async_mode = 'gevent'
        except ImportError:
            pass

    if async_mode is None:
        async_mode = 'threading'

    print('async_mode is ' + async_mode)

# monkey patching is necessary because this application uses a background
# thread
if async_mode == 'eventlet':
    import eventlet
    eventlet.monkey_patch()
elif async_mode == 'gevent':
    from gevent import monkey
    monkey.patch_all()


import time
from threading import Thread, Lock
from flask import Flask, render_template, session, request
from flask_socketio import SocketIO, emit, join_room, leave_room,close_room, rooms, disconnect
import sys
import glob
import serial
import json
import struct


import csv

#Version 2.7 or Above?
if sys.version_info[0] >2:
    version3 = True
    kwargs = {'newline':''}
else:
    version3 = False 
    kwargs = {}



##import logging
##log = logging.getLogger('werkzeug')
##log.setLevel(logging.ERROR)



serialConnected = False #global flag for whether or not the serial port should be connected
serialPort =0  # (init value is 3...junk) contains serial port object when in use...touching protected by serialLock below
serialLock = Lock() #serial permission lock (protects shared resource of serial port)
print (serialLock)

#Taken from here on StackExchange: http://stackoverflow.com/questions/12090503/listing-available-com-ports-with-python
#Want to give credit where credit is due!
def serial_ports():
    if sys.platform.startswith('win'):
        ports = ['COM%s' % (i + 1) for i in list(range(256))]
    elif sys.platform.startswith('linux') or sys.platform.startswith('cygwin'):
        # this excludes your current terminal "/dev/tty"
        ports = glob.glob('/dev/tty[A-Za-z]*')
    elif sys.platform.startswith('darwin'):
        ports = glob.glob('/dev/tty.*')
    else:
        raise EnvironmentError('Unsupported platform')

    result = []
    for port in ports:
        try:
            #print("checking port "+port)
            s = serial.Serial(port)
            #print("closing port "+port)
            s.close()
            result.append(port)
        except (OSError, serial.SerialException):
            pass
    return result
#-------------------

#serial variables:

serialselection = ''
#baudselection = 115200
baudselection = 230400

mcuMessage = []


'''system_parameters (dictionary where keys are user-variable parameters and entry is list consisting of current value (index 0 and single-character comm term for conveying value back to micro...for example you could have system_parameters['K_d']=[1.4,'D']
'''
system_parameters = {} 
#params_and_values an ordered list of the names of paramters, headroom, and values to be plotted
#Used in generating CSV header list in order
params_and_values = []
#A list pointing to parameter values for quick plotting (rather than list comprehend this every time
param_vals = []

command_terms = ['HIHI']

#expected_length...how long each full message from Micro should be
expected_length = 0
#function that will be stored for chopping up message into appropriate signed/unsignedness/float, etc... makes this processing arbitrarily expandable as needed...must obviously agree with encoding scheme on micro
parseFunction = lambda x: [0]
'''Kp = 0.0
Kd = 0.0
Ki = 0.0
direct = 0.0
desired = 0.0
alternate = 0.0 # global flag of whether or not we're alternating...
'''


#ALTERNATING DATA STRUCTURE:
#   timer and state are used for storing/remembering the switching action
#   period is how often to switch (in seconds)
#   param is the user input that is switched (determined during initialization)
alt_data = {'timer': time.time(), 'state':-1.0, 'period': 5, 'param': None} #data struture used to implement alternating behavior

#Start up Flask server:
app = Flask(__name__, template_folder = './',static_url_path='/static')
app.config['SECRET_KEY'] = 'secret!' #shhh don't tell anyone. Is a secret
socketio = SocketIO(app, async_mode = async_mode)
thread = None

#csv variables:
global csv_default
global csv_recent
global current
global archive
csv_st = time.time()
#variable which determines whether a csv is being generated or not.
csv_yn = False  #start out not writing csv files
csvLock = Lock()

keepRunning = True #set to True for default


#global setup variables:
#used during initialization of comms/building GUI
isSetup = False
setupString = ""
allGoodFromGUI = False
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

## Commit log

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2016-09-03 Tradeoff processors
    [micro.xlsx]
2016-09-09 Time trace
    [fr_of_0p1s_1st_order_filter_time.xlsx]
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2016-09-11 Analyze lates sweep
    [fr_time_20160909.xlsx]
2016-09-14 Prototype Response
    [calibration20160913.xlsx, frFan_20160913.xlsx, frFan_20160913a.xlsx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]
2016-09-15 update spreadsheet calibration
    [calibration20160913.xlsx]
2016-09-15 Working Closed Loop
    Either Freq Resp or Ref following by changine #define at top
    [50mmCal.xlsx, frFan_90160915a.xlsx]
2016-09-26 15a tune
    [frFan_90160915a.xlsx]
2016-09-26 Measure power
    [calibration20160913.xlsx]
2016-09-26 10 uF cap FR
    [calibration20160913.xlsx, frFan_20160926_10uFcap.xlsx]
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2016-10-01 Rescale Nf
    [calibration20160913.xlsx]
2016-10-01 Arduino Freq Resp
    [frFan_20161001a.xlsx]
2016-10-01 rigorous calibration
    [calibration20160913.xlsx]
2016-10-02 debug freq resp Arduino
    [frFan_20161001b.xlsx]
2016-10-02 debug closed loop cleanup
    [calibration20160913.xlsx, fanTime_20161002b.xlsx, timeFan_20161002a.xlsx]
2016-10-02 cal cleanup
    [calibration20160913.xlsx]
2016-10-05 freq resp repeated presses fix
    [arduinoESC.fzz]
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2016-10-09 Documentation Changes updates for Arduino
    [arduinoESC.fzz, calibration20160913.xlsx, frFan_20161001b.xlsx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]
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2016-10-13 debug tables and get Turnigy to run
    [calibration20161009.xlsx, calibration20161012.xlsx]
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2016-10-14 Nf Ref for Ng=0
    [calibration20161009a.xlsx, calibration20161012.xlsx]
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2016-10-14 drive th to zero at startup
    to support hitec esc
    [calibration20161009.xlsx, calibration20161012.xlsx]
2016-10-15 compare HiTec to new Turnigy
    close enough. model needs work
    [calibration20161012.xlsx, fr_OL_A_H_30_10.xlsx, fr_OL_A_T_30_10.xlsx]
2016-10-15 Calibrate Turnigy
    good match. One freq resp result
    [calibration20161012.xlsx, fr_OL_A_T_30_10.xlsx]
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2016-10-16 Effect of backpressure illustrated
    [calibration20161012.xlsx]
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2016-10-20 Revert "some fr data"
    This reverts commit df0b1481bfb5ab57e968bc4bd8c80667b36ac634.
    [calibration20161019.xlsx, fr_OL_A_T_461_50_03_1.xlsx, fr_OL_A_T_461_50_03_2.xlsx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]
2016-10-20 Revert "Revert "some fr data""
    This reverts commit 88f0b54263ff8b206aaeb62a5ab3ff6636e9d12b.
    [calibration20161019.xlsx, fr_OL_A_T_461_50_03_1.xlsx, fr_OL_A_T_461_50_03_2.xlsx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]
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2016-10-21 fr data off design
    [fr_OL_A_T_461_50_06_3x.xlsx]
2016-10-22 Bare motor and F2V Capacitor Runs
    0.1 second F2V filter characterized. 0.02-0.125 second fan rotor lag
    characterized
    [calibration20161019.xlsx, fr_OL_A_T_461_50_03_1.xlsx]
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2016-10-24 Fit data to Fan Tau
    Calculated Ng Tau fits better than reverse flow data
    [calibration20161019.xlsx]
2016-10-25 Tweak J to Match Tau Data
    Fudge no matter how you slice it
    [calibration20161019.xlsx]
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2016-10-27 First Working Gain Scheduled Control
    [calibration20161019.xlsx, firstRealCL_20161026.xlsx, microturbineManifast20160930.xlsx]
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2016-11-05 Work on verification
    need motor inertia. Need to add B damp windage
    [calibration20161019.xlsx]
2016-11-06 Power collapses the time constants
    [calibration20161019.xlsx, fr_A1_T1_M1_60_6_20161103.xlsx]
2016-11-08 Fix calibration - speed cubed to power
    [calibration20161019.xlsx]
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2016-11-13 Begin to Analyze LM2907
    [calibration20161019.xlsx]
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2016-11-19 Retune with delays correct
    [calibration20161019.xlsx, fr_OL_P_T_461_var_06_1ms.xlsx, matlabTuning.xlsx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]
2016-11-20 verification
    hi power oscillation
    [fr_OL_P_T_461_var_06_1ms.xlsx, fr_P1x_T1x_65_06.xlsx, fr_header.xlsx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]
2016-11-20 new data T1x
    Had to limit max throttle for T1x device
    [tf_P0_T0_G0_T0_20161119.csv, tr_P1x_T1x_G1x_20191120.csv]
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2016-11-30 24 point freq resp; exponential lag fixed
    [fr_model_intervals.xlsx]
2016-12-03 fixed lead tuning
    [matlabTuning.xlsx]
2016-12-03 add fixed lead option
    [matlabTuning.xlsx, trSweep_P1x_T1x_G1x.xlsx]
2016-12-04 symbolic link to Arduino created
    [arduinoESC.fzz]
2016-12-07 make data sheet for data cal bench testing
    [calibration20161019.xlsx, calibration20161207.xlsx]
2016-12-07 fix wire routing on fzz
    [arduinoESC.fzz]
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2016-12-12 Cal all 4; need to rewire POT and recal throttle
    meas last point in cal too
    [calibration20161207.xlsx, fr_a3_t3_e3_g3b_t3a.xlsx, fr_a4_t4_e4_g4b_t4a.xlsx]
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2016-12-13 cal complete incl transients
    [calibration20161207.xlsx, tr_20161213_1_1.xlsx, tr_20161213_2_1.xlsx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]
2016-12-14 Cross plot kit 1
    need to swap out ESC for Kit 1
    [calibration20161207.xlsx, tr_20161213_1_1.xlsx]
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2016-12-15 Recal Kit1
    still some oscillation
    [calibration20161207.xlsx, tr_20161215_1_1.xlsx]
2016-12-15 Recal Kit 1 new ESC
    [calibration20161207.xlsx]
2016-12-16 retest 1
    5th order poly fits gain best
    [calibration20161207.xlsx, tr_20161216_1_1.xlsx]
2016-12-17 fix figure
    [arduinoESC.fzz, tr_20161215_1_1.xlsx]
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2016-12-17 recal photon for non-linear throttle end
    [calibration20161207.xlsx]
2016-12-18 Throttle table for Photon
    Need to verify
    [calibration20161207.xlsx]
2016-12-20 limit throttle because v4 non-linear
    Photon and A1
    [calibration20161207.xlsx]
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2016-12-25 add attenuator to circuit
    [arduinoESC.fzz, photonESC.fzz]
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2016-12-25 vector to Arduino
    Doesn't work. Make local in potESC
    [calibration20161207.xlsx]
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2017-01-04 gain study; also inv noise a1
    [arduinoWind.fzz, calibration20161207.xlsx, fr_a1_t1_e1_g1b_t1a.xlsx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]
2017-01-04 test feature. Ready to calibrate A0
    [calibration20161207.xlsx]
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2017-01-05 cal A0 - don't use it. Put A0 into kit 1
    [calibration20161207.xlsx, fr_a0_t0_e0_g0b_t0a.xlsx]
2017-01-05 v1 first of day. Swapped in A0 to Kit 1
    [v1_ct0_20170105.csv]
2017-01-05 redo v1, no rate limit closed loop
    [tr_header.xlsx, v1_ct0_20170105.csv]
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2017-01-06 tweak calibration - need to redo A2 with ESC calibrated and 180 deg
    [calibration20161207.xlsx]
2017-01-07 RAMP test complete - only closed loop, same as VECT
    [r_p1_ol.xlsx]
2017-01-08 bare || test do not write to servo
    [r_p1_ol.xlsx]
2017-01-11 KIT 99 in Cal file
    [calibration20161207.xlsx]
2017-01-12 verify v1
    still have THTL limited to 5 degrees!!!why?
    [v1_ct1_a1_20170112.csv, v1_ct1_test_20170112.csv]
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2017-01-13 verify A2
    added attenuator circuit and use model <18 degrees
    [calibration20161207.xlsx, r2_ct1_ol_attenRecal_20170113.csv, r2_ct1_ol_atten_20170113.csv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]
2017-01-14 v3
    should disconnect osc from Nt when measuring v4
    [calibration20161207.xlsx, r3_ol_20170114.csv, t3_ct1_20170114.csv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]
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2017-01-17 v5 with 100/220 ohms
    [fr_a4_t4_e4_g4b_t4a.xlsx, r5_ol_20170117.csv, v5_ct1_20170117.csv]
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2017-01-20 minor bug fix
    [calibration20161207.xlsx]
2017-01-23 minor bugs
    [calibration20161207.xlsx, r1_ol_20170123.csv, t1_ct1_20170123.csv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]
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
